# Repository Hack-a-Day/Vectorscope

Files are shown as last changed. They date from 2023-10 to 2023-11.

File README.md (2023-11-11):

# Hackaday Superconference 2023 Vectorscope Badge

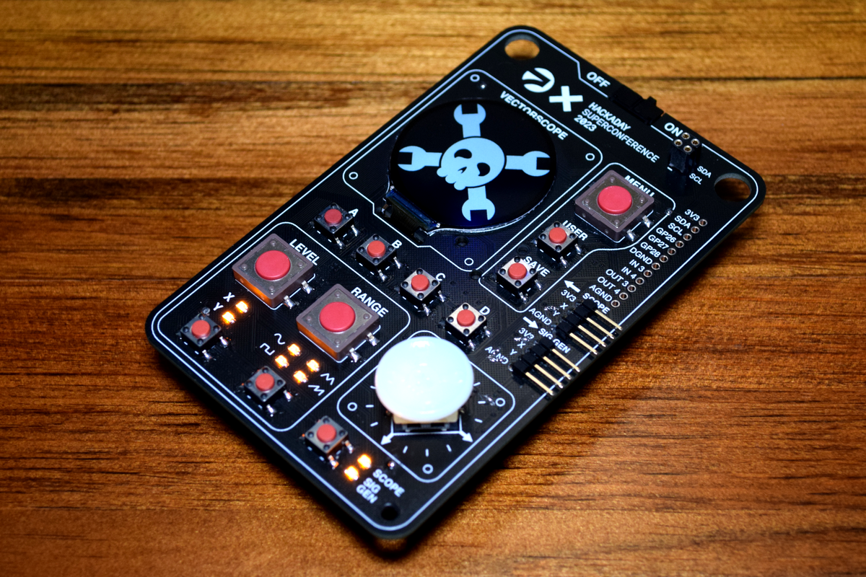
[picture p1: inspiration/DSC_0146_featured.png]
Vectorscope


## Related articles

* [Hackaday Teaser](https://hackaday.com/2023/10/18/2023-hackaday-supercon-badge-welcome-to-the-vectorscope/)
* [Hackaday Printable case](https://hackaday.com/2023/10/29/packing-for-supercon-heres-a-printable-case-for-your-badge/)

## Getting started

### IDEs

#### Thonny

This is a relatively simple IDE, more or less designed specifically for MicroPython, and does most of the stuff you would need, without hiding functionality.

It's pretty easy to install at get started with, not least because you can access and open up files directly on the badge, edit them and save them back on the badge.

See the [Thonny getting started](setup/README.md#Thonny) for a little more info.

#### VSCode and the MicroPico extension

If you already use VSCode, the MicroPico extension and a few other recommended extensions might be an option, especially if you are used to have projects and work with both a set of files on you computer and on the badge. There is a bit more setup required to get going, but you get a bit more functionality in areas like code completion and direct access to documentation for various functions.

See the [VSCode getting started](setup/README.md#VSCode) for a little more info and setup help.

#### Your favorite text editor and mpremote

If you don't like integrades development environments (IDEs), you can also use your favorite text editor and mpremote for communication with the badge.

We have a few [tips and tricks with mpremote](setup/README.md#mpremote) to get you started.

## Repository overview

### Firmware

This folder has the MicroPython firmware for the Raspberry Pi Pico on the badge in a special edition, that includes the driver for the GC9A01 display controller and some of the latest additions needed for DMA on the RP2040.

The ```.uf2``` file can be used to restore the badge, if you have tried other code and want to revert back to the original state. In addition to the ```.uf2``` firmware file, you will also need the original MicroPython code and assets for a full restore.

### Hardware

The hardware folder is where you will find all the details about the main PCB, the expansion board and the parts that are on the main board. There is schematics as a few images, and data sheets for the parts used. Especially the Pico [datasheet](hardware/datasheets/pico-datasheet.pdf?raw=true) or the [pinout](hardware/datasheets/pico_pinout.png?raw=true) can be usefull as a references, if you want to have a go at doing some hacks outside of the normal.

The design is done in Altium Circuit Maker and in addition to the [board file](hardware/vectorscope/vectorscope.CSPcbDoc?raw=true), there are also Gerbers, drill files and a BOM, in case you want to make your own or maybe just have a peak and check some traces.

There is also a WiP (Work in Progress) version of the [board file i KiCad format](hardware/vectorscope/vectorscope.kicad_pcb?raw=true). It's not perfect as some of the conversion didn't go perfect (eg. incorrect ground plane size and connections), but for mechanical use (eg. case design) it should be OK, though not all 3D models are available in the default KiCad repository.

If you want to build you own based on the Gerbers here some notes:
- T1 needs to be solderd flipped (deadbug) and rotated. Like in this image. You see the backside of the Fet. Pins need to get bend a little bit.

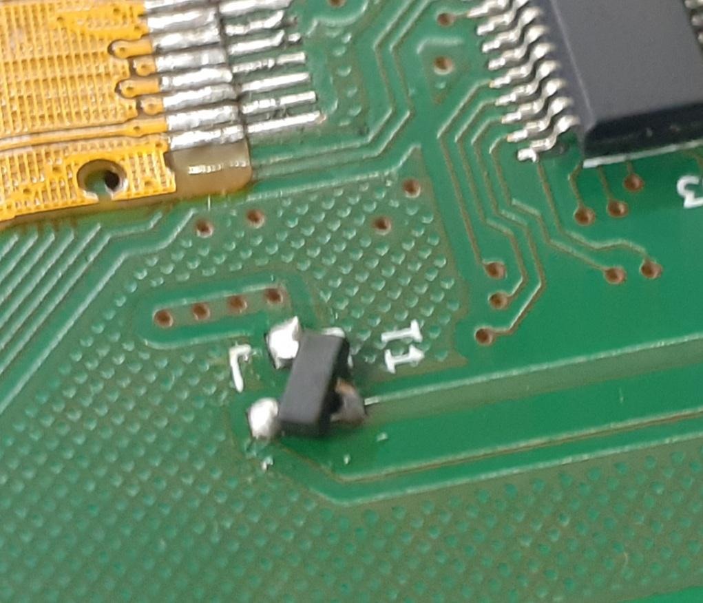
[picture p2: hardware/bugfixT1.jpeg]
bugFixT1


### Inspiration

We'd been thinking of doing something analog this year, because we've been heavily digital with the [2019 FPGA badge](https://hackaday.com/2019/11/04/gigantic-fpga-in-a-game-boy-form-factor-2019-supercon-badge-is-a-hardware-siren-song/) and [last year's virtual retrocomputer](https://hackaday.com/2022/10/12/the-2022-supercon-badge-is-a-handheld-trip-through-computing-history/).  [Sebastian Holzapfel]'s [Eurorack FPGA frontend](https://hackaday.com/2023/02/13/an-open-hardware-eurorack-compatible-audio-fpga-front-end/) showed us how to abuse the AK4619 ADC/DAC chip for DC voltage purposes, and our path was clearer still.  

Finally, [Schneider] showed us the prototypes for the [flow3r badge for this summer's Chaos Camp](https://flow3r.garden/) in [Berlin](https://hackaday.com/2023/03/27/hackaday-berlin-was-bonkers/), and we needed to make a vintage round-screen scope.  Besides, we'd been looking for an excuse to try out those round screens since seeing [Scott Bezek]'s [SmartKnob](https://github.com/scottbez1/smartknob).  How could we resist?

## Related projects

- [BASIC-2 enclosure](https://github.com/softegg/supercon-2023-badge-enclosure/tree/main/BASIC-2) by Tina Belmont

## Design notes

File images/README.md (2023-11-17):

Here you'll find some `uf2` images that you can copy directly to the badge when it's mounted in bootloader / USB-disk mode.  (Hold the Pico's boot button while plugging in.)

The images in micropython_compiled/ are a preview version of v1.22.0, with a driver for the GC9A01 screen and pull release for DMA support compiled in.  This is here really just in case you want to play around, or if you've soldered on a Pico W, which requires its own firmware.

The Supercon image includes our modified Micropython and all of the various python code that makes it run.

Note that flashing the Supercon `uf2` will probably wipe anything you have on the device, so save your work first.  Heck, save your work right now anyway.  You never know!

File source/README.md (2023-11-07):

# Supercon 2023 Source Code

This directory contains the source files for the 2023 Supercon Badge. When possible, changes from the initial day-one release are listed below.

## Changes
- supercon_menu.py: Fixed crash in scope mode
- led.py: Added from Vector OS docs
- keyboardrepeat.py - Added from Vector OS docs

- Tagged as V1.0

- Added BETA/*.py files to source and removed BETA directory
  Note: this means the UF2 matches V1.0 not current
  development files

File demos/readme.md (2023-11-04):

VectorOS Demos
==============

* blinker.py - Obligatory LED blinker
* csvdemo.py - Paste numbers from a spreadsheet, view on scope
* csvfile.py - Read data.dat (Y values), view on scope
* csvfilexy.py - Read dataxy.dat (X,Y values), view on scope
* hello.py - File from tutorial
* life.py - Slow game of life (needs work)
* simple.py - Another LED blinker (very simple)

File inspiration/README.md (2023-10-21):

# Vectorscope Inspiration

We'd been thinking of doing something analog this year, because we've been heavily digital with the [2019 FPGA badge](https://hackaday.com/2019/11/04/gigantic-fpga-in-a-game-boy-form-factor-2019-supercon-badge-is-a-hardware-siren-song/) and [last year's virtual retrocomputer](https://hackaday.com/2022/10/12/the-2022-supercon-badge-is-a-handheld-trip-through-computing-history/).  [Sebastian Holzapfel]'s [Eurorack FPGA frontend](https://hackaday.com/2023/02/13/an-open-hardware-eurorack-compatible-audio-fpga-front-end/) showed us how to abuse the AK4619 ADC/DAC chip for DC voltage purposes, and our path was clearer still.  

Finally, [Schneider] showed us the prototypes for the [flow3r badge for this summer's Chaos Camp](https://flow3r.garden/) in [Berlin](https://hackaday.com/2023/03/27/hackaday-berlin-was-bonkers/), and we needed to make a vintage round-screen scope.  Besides, we'd been looking for an excuse to try out those round screens since seeing [Scott Bezek]'s [SmartKnob](https://github.com/scottbez1/smartknob).  How could we resist?

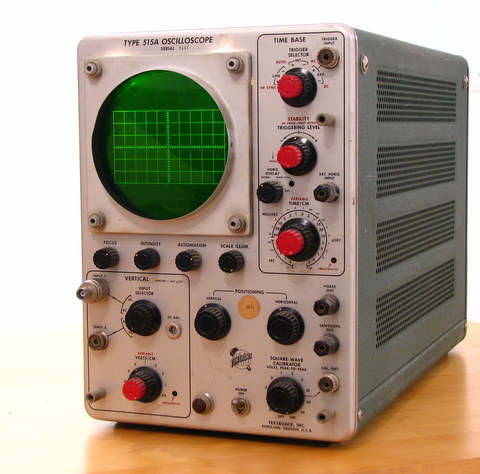
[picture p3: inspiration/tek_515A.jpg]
Tek 515A


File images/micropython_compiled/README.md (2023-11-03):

Firmware images for the Micropython builds for the badge.  These are just the Micropython, none of our badge code.

Note these come in Pico and Pico_W flavors.  Choose wisely.

These are compiled with [gc9a01_mpy](https://github.com/russhughes/gc9a01_mpy) screen driver and [a recent pull request](https://github.com/micropython/micropython/pull/7641) that provides interrupt request support for the DMA subsystem.

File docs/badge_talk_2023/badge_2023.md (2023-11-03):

# Supercon 2023: The Vectorscope Badge

# Overview

## The Badge

- What is It?

- How Does it Work?

- Can I Hack It?

## Inspiration: Analog



## One Badge, Two Parts

- Vectorscope: 30 kHz "scope"

- Signal Generator: Driven by code 

- X/Y outputs, X/Y inputs (0 V - 3 V)

## Vectorscope

- Fake phosphor display 

- "No User-Serviceable Parts Inside"

- AK4619 Codec chip (`codec.py`)

- ADC in, 16 frames of 1024 samples (16-bit X/Y)

- Insane DMA/PIO Machine (`pixel_pusher.py`)

- Twelve lines of user-space code (`vectorscope.phosphor()`)

## Signal Generator

- DAC out

- Limitations: 30 kHz, ringy filter, one CPU core

- X/Y buffers, 256 points @ 16 bits, interleaved and pushed out

- This is your playground (`waveform.py`)

## Signal Generator "API"

- `v.wave.point(x,y)`  

- `v.wave.packX(list)`, `v.wave.packY(list)`

- `v.wave.outBuffer_ready`: 

- write False, wait till True

## Operating System

- Vectoros!

- Runs menu system

- Buttons and LEDs

- Uses `asyncio`: define functions `async` and be sure to yield

- Lets you map your code to `A/B/C/D.py`

## Micropython

- Why Micropython?

- Interactive REPL to control vectorscope is awesome

- Two cores: one just for you

- Filesystem

- Secret trick: Hold down the [User] Button on boot

## Creature Comforts

- Thonny IDE: configure to use badge, done

- mpremote: for the CLI aficionado

- `mp run file.py`, `mp cp *.py :`, `mp mount .`

- `picotool save -a your_image.uf2`

- VS Code stubs

## Many Ways to Play

- Use `vectorscope.wave`, funny graphics and/or sounds

- Go analog!

- Tweak vectorscope 

- Don't use vectorscope: GC9A01_mpy library compiled in

- Blow Micropython away and start from scratch (but: codec, screen, keys)

# Under the Hood

## Credits

- Hackaday Team: Elliot and Al and Tom

- Voja Antonic

- Design Lab: Giovanni, Majenta, Bruce, Keno, and Team 

## Tales of Woe 

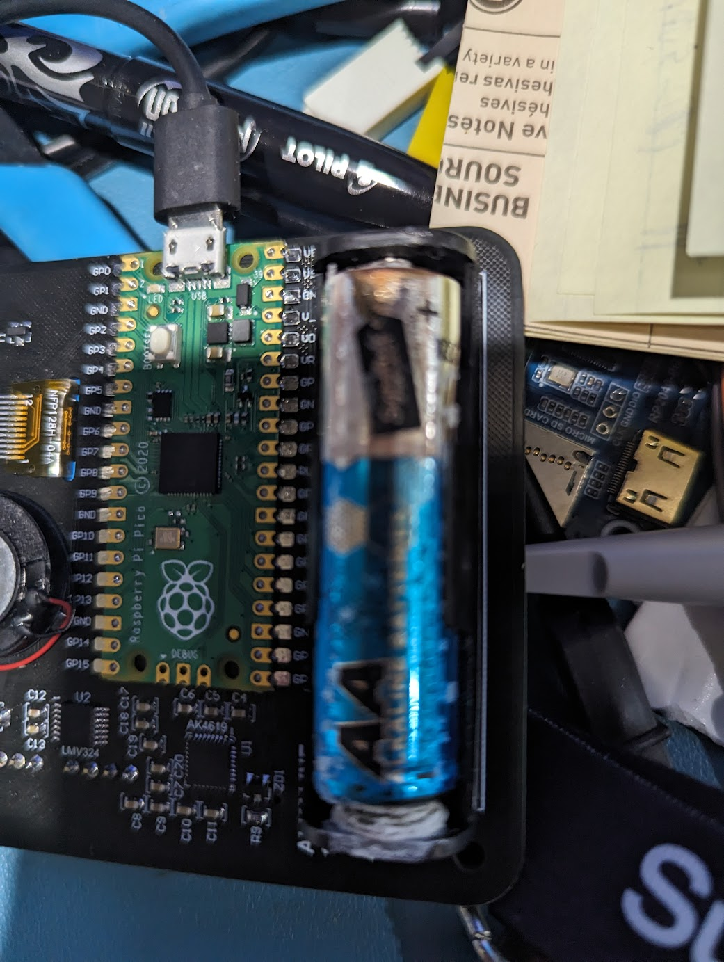
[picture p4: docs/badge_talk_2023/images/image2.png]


## Powers of Ten

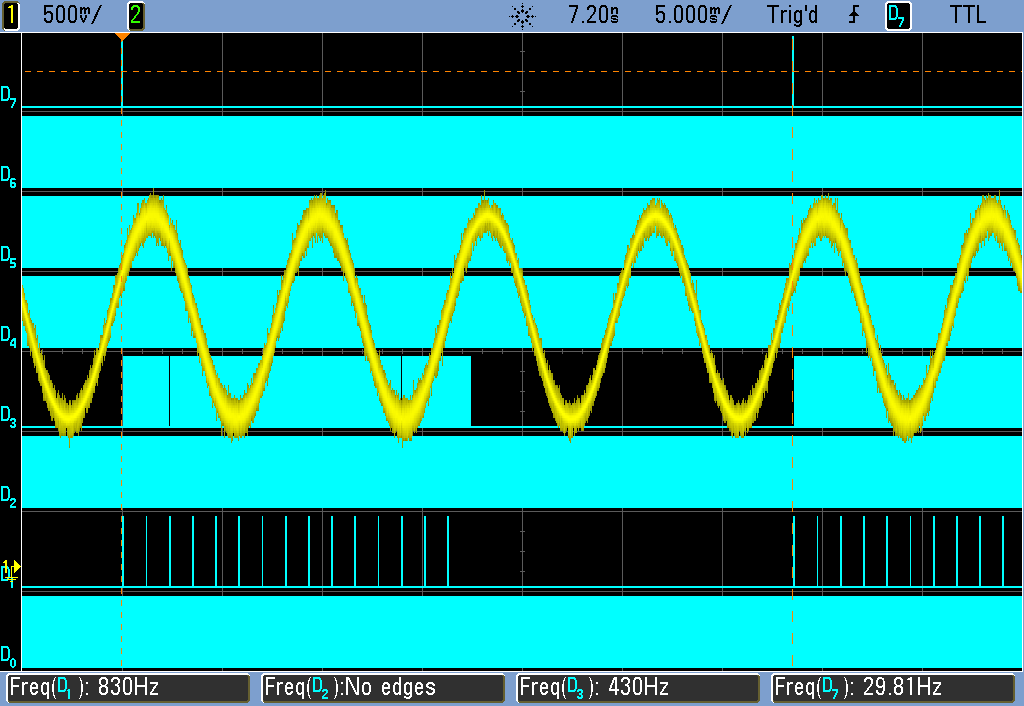
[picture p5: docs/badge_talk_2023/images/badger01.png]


## 10 ms
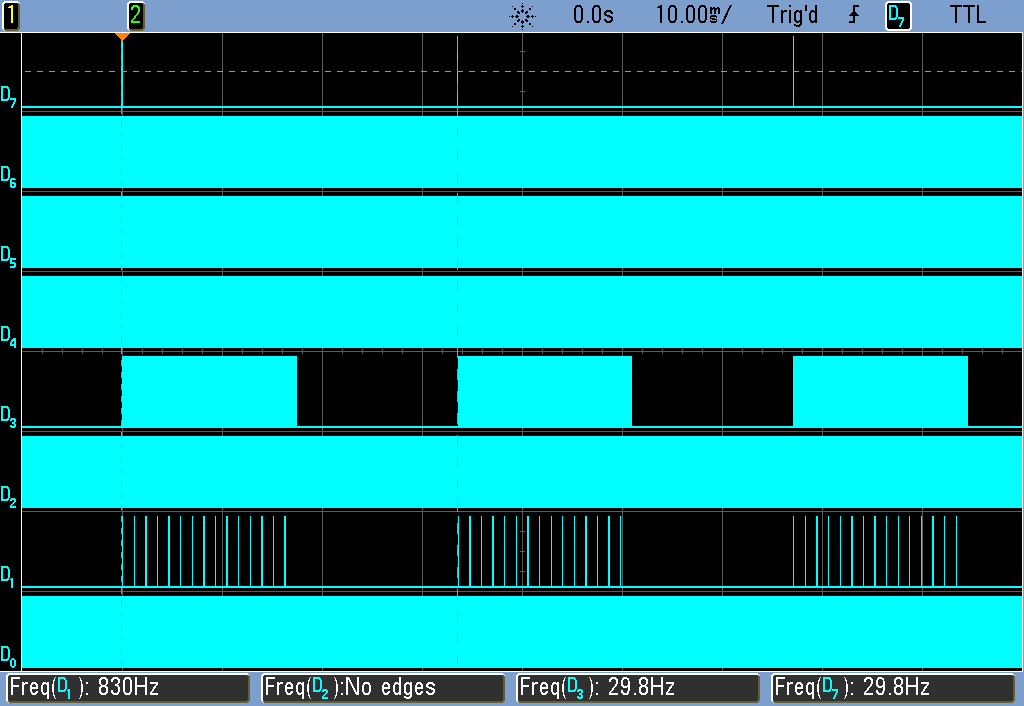
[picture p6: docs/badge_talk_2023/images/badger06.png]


## 1 ms
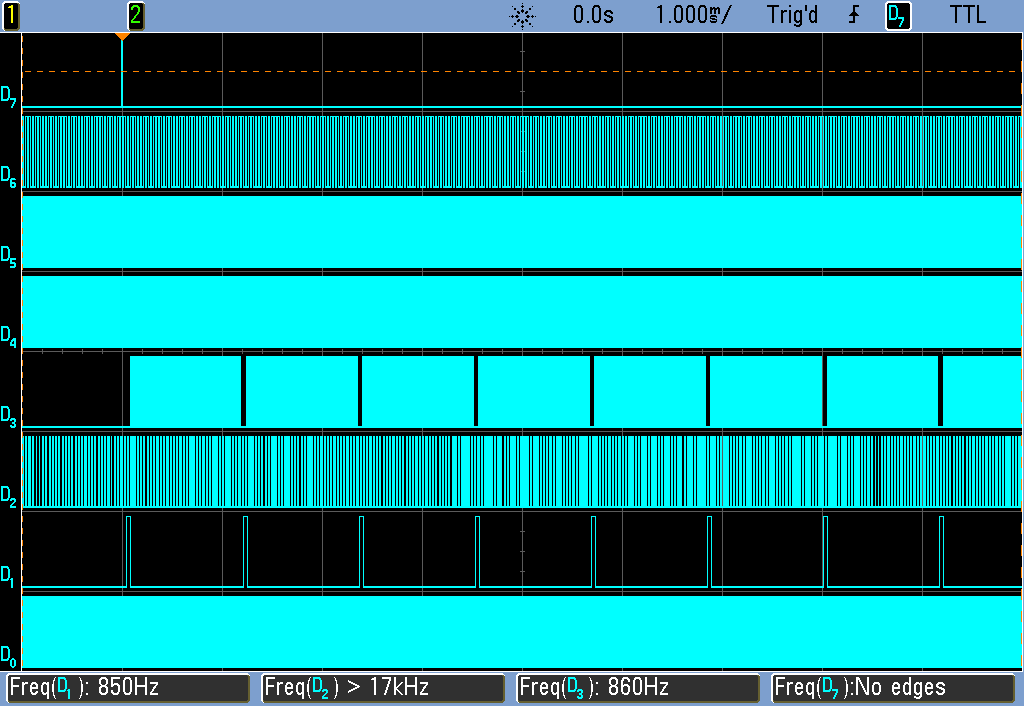
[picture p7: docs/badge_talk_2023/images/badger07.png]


## 100 us
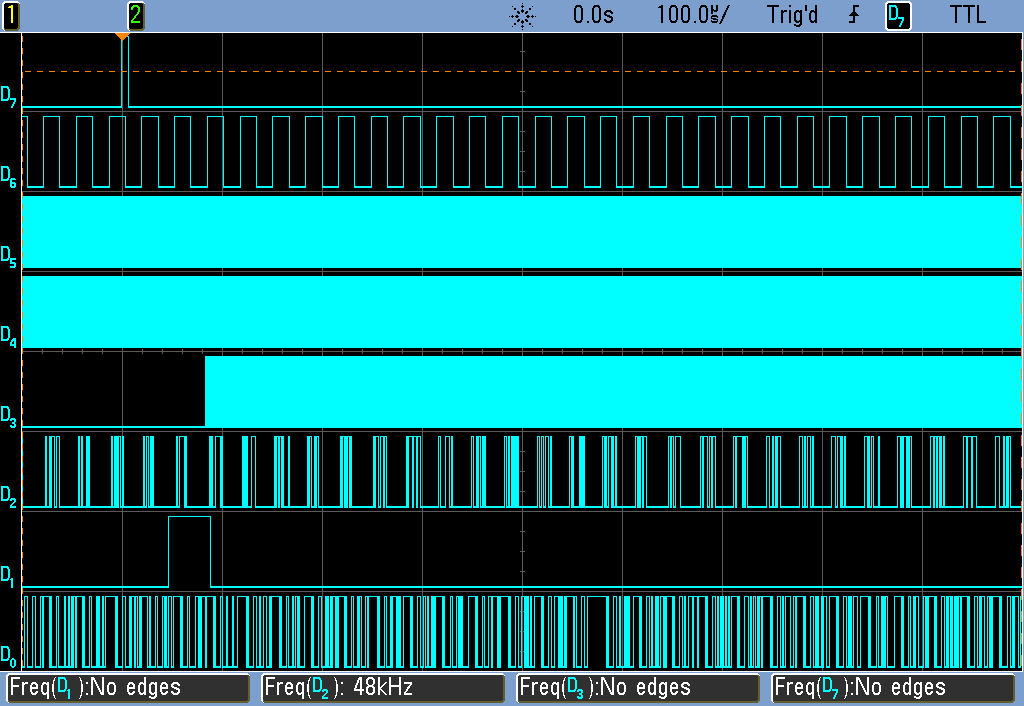
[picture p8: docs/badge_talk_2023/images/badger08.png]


## 10 us
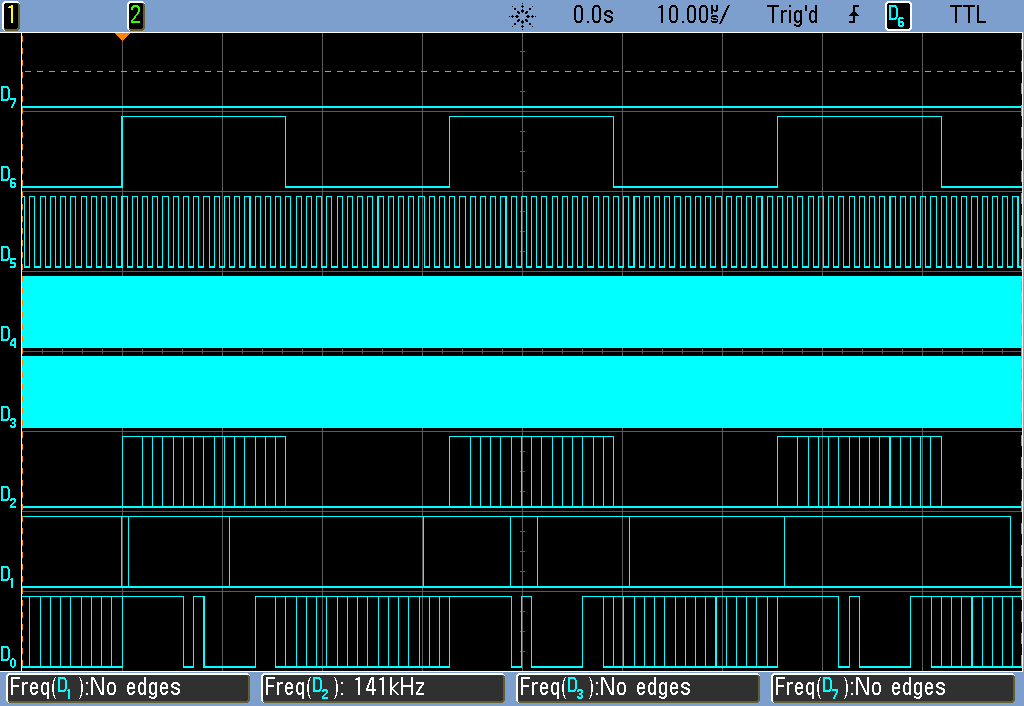
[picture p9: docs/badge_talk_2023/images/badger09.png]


## 1 us
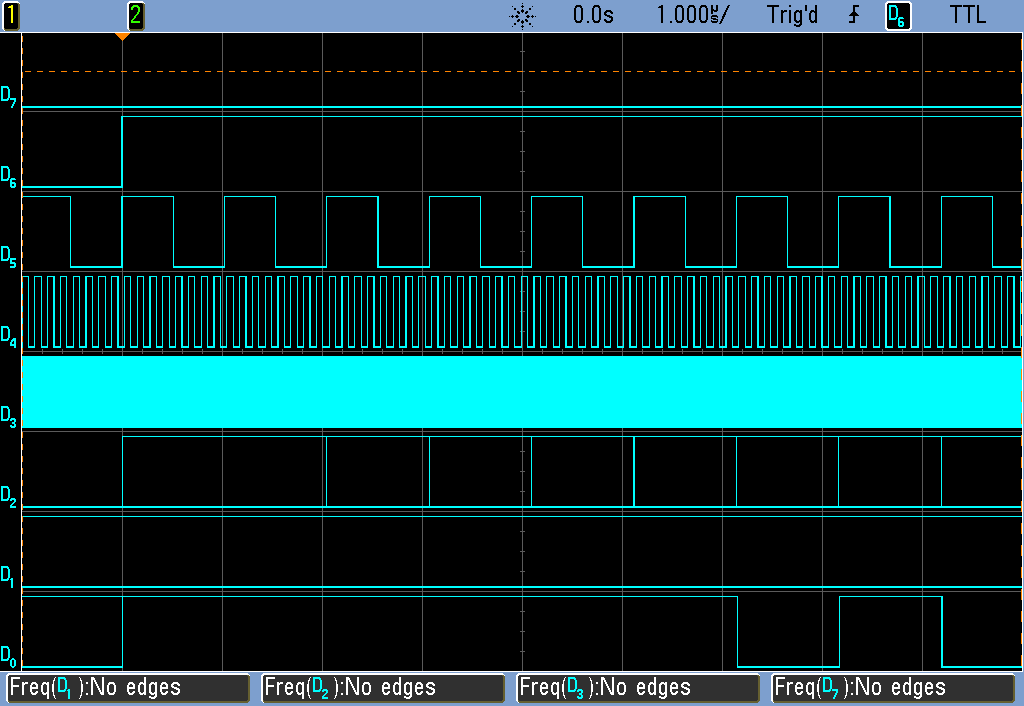
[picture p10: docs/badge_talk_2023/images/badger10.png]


## 100 ns
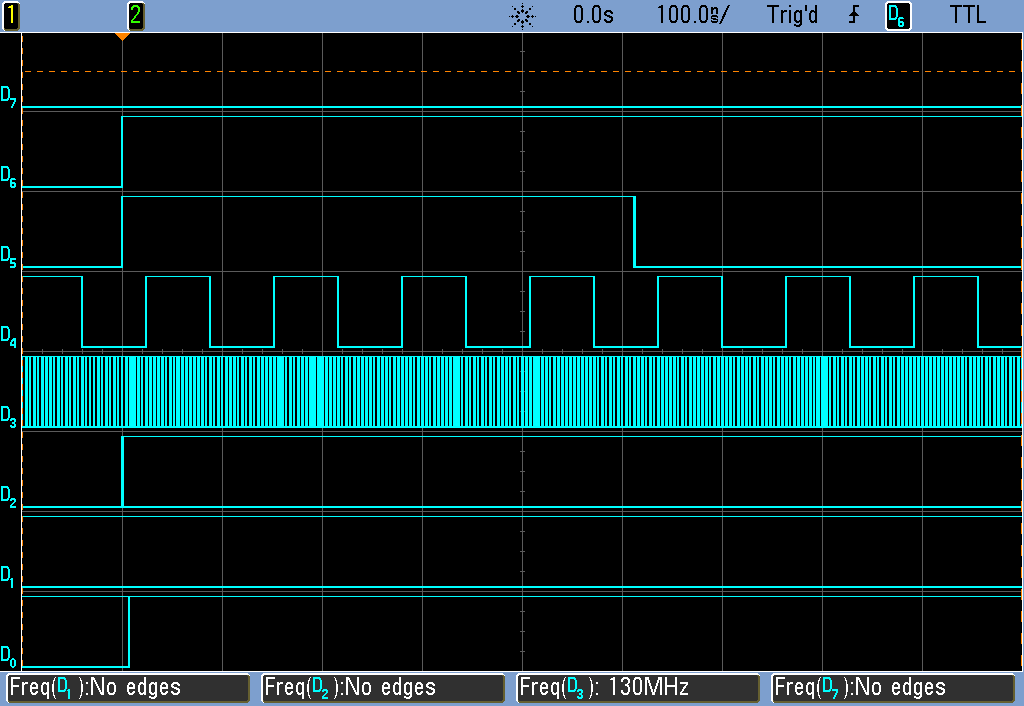
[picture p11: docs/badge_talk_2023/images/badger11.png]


## 10 ns
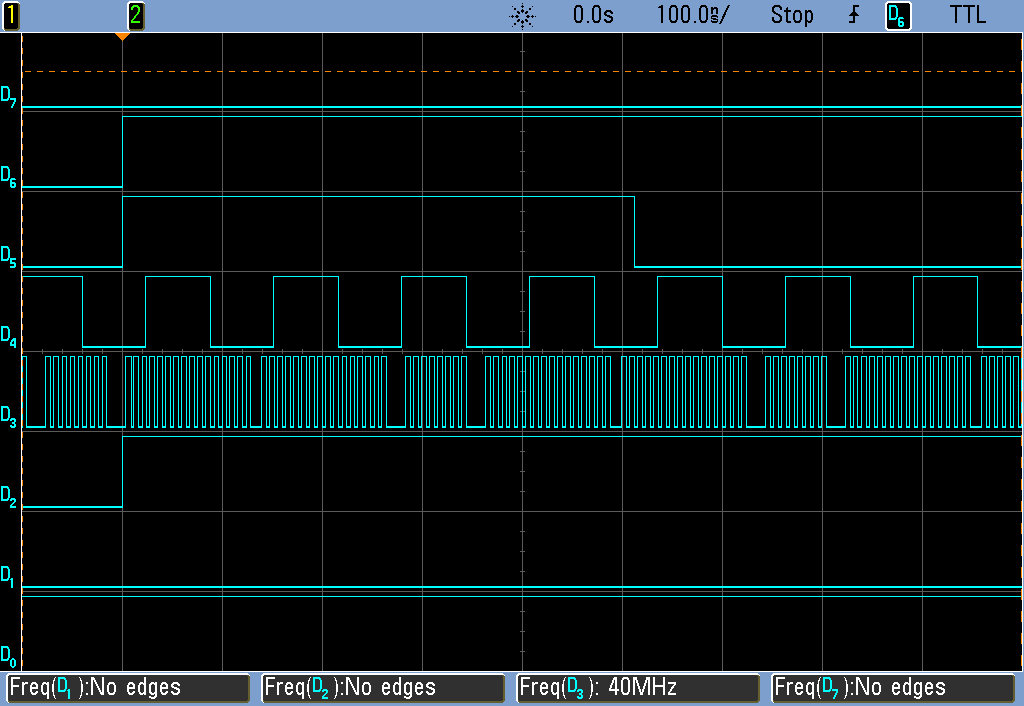
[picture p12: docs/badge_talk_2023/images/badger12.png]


## 1 ns
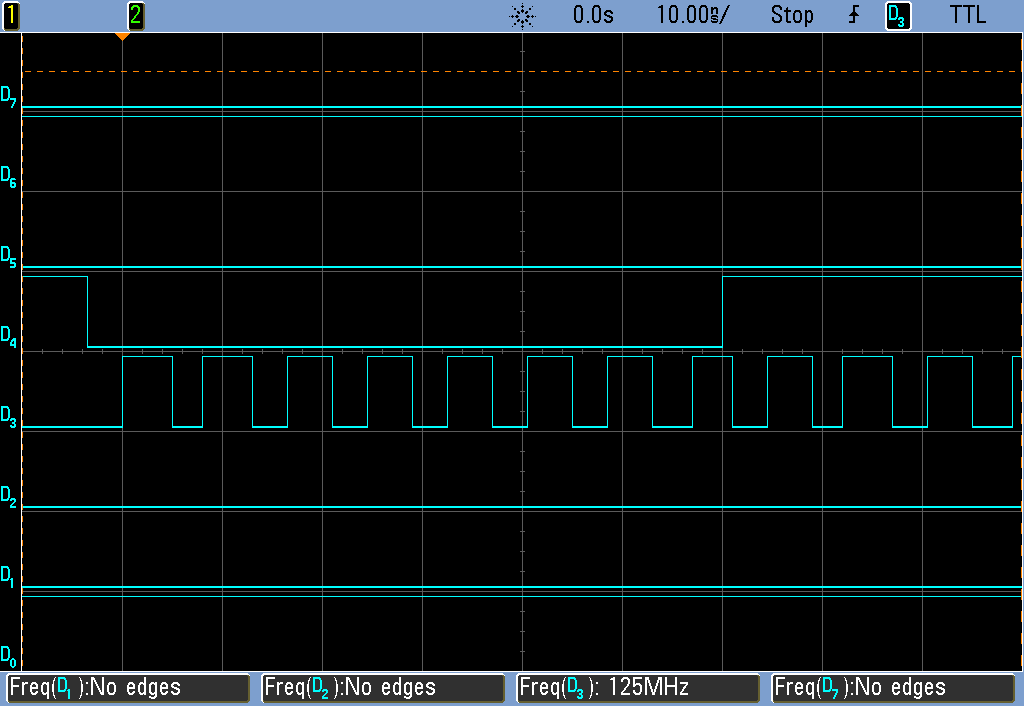
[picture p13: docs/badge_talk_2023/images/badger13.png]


## The DMA/PIO Machine

- DMA reads from one location to another

- DMA and memory is Turing complete

- DMA counter

## Pixel Pusher

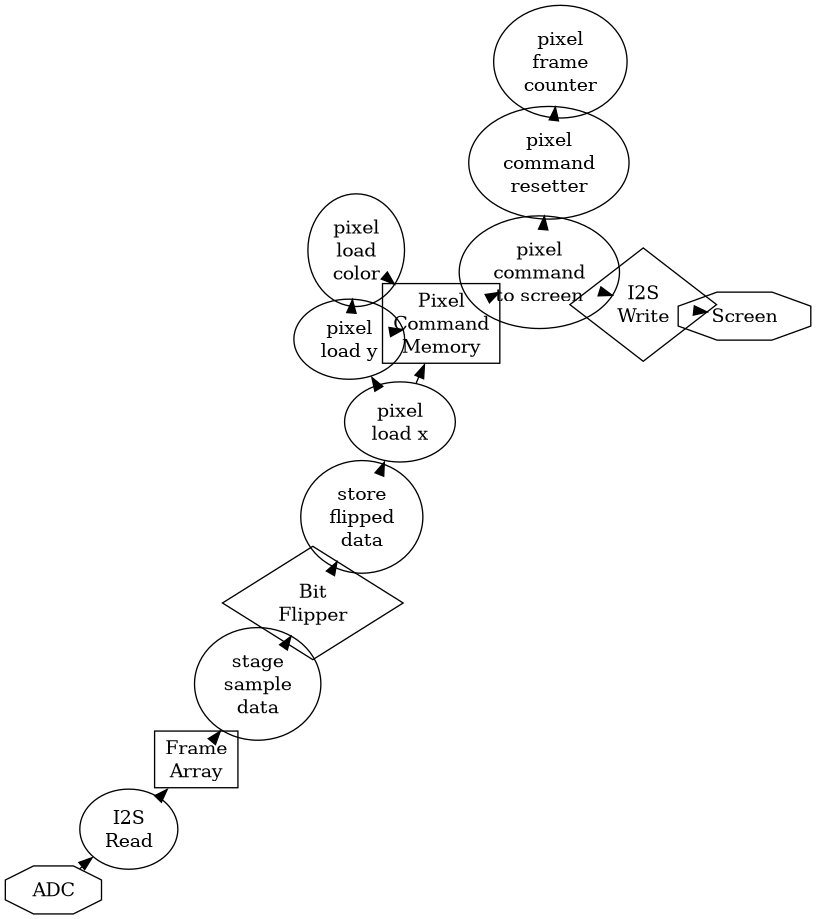
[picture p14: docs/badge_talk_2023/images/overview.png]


# Badgers!

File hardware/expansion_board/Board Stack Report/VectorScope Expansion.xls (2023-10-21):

Board Stack Report
Stack Up |  | Layer Stack
Layer | Board Layer Stack | Name | Material | Thickness | Constant
1 |  | Top Paste
2 |  | Top Overlay
3 |  | Top Solder | Solder Resist | 1.00mil | 3.5
4 |  | Top Layer | Copper | 1.40mil
5 |  | Dielectric 1 | FR-4 | 60.00mil | 4.6
6 |  | Bottom Layer | Copper | 1.40mil
7 |  | Bottom Solder | Solder Resist | 1.00mil | 3.5
8 |  | Bottom Overlay
9 |  | Bottom Paste
 | Height : 64.80mil

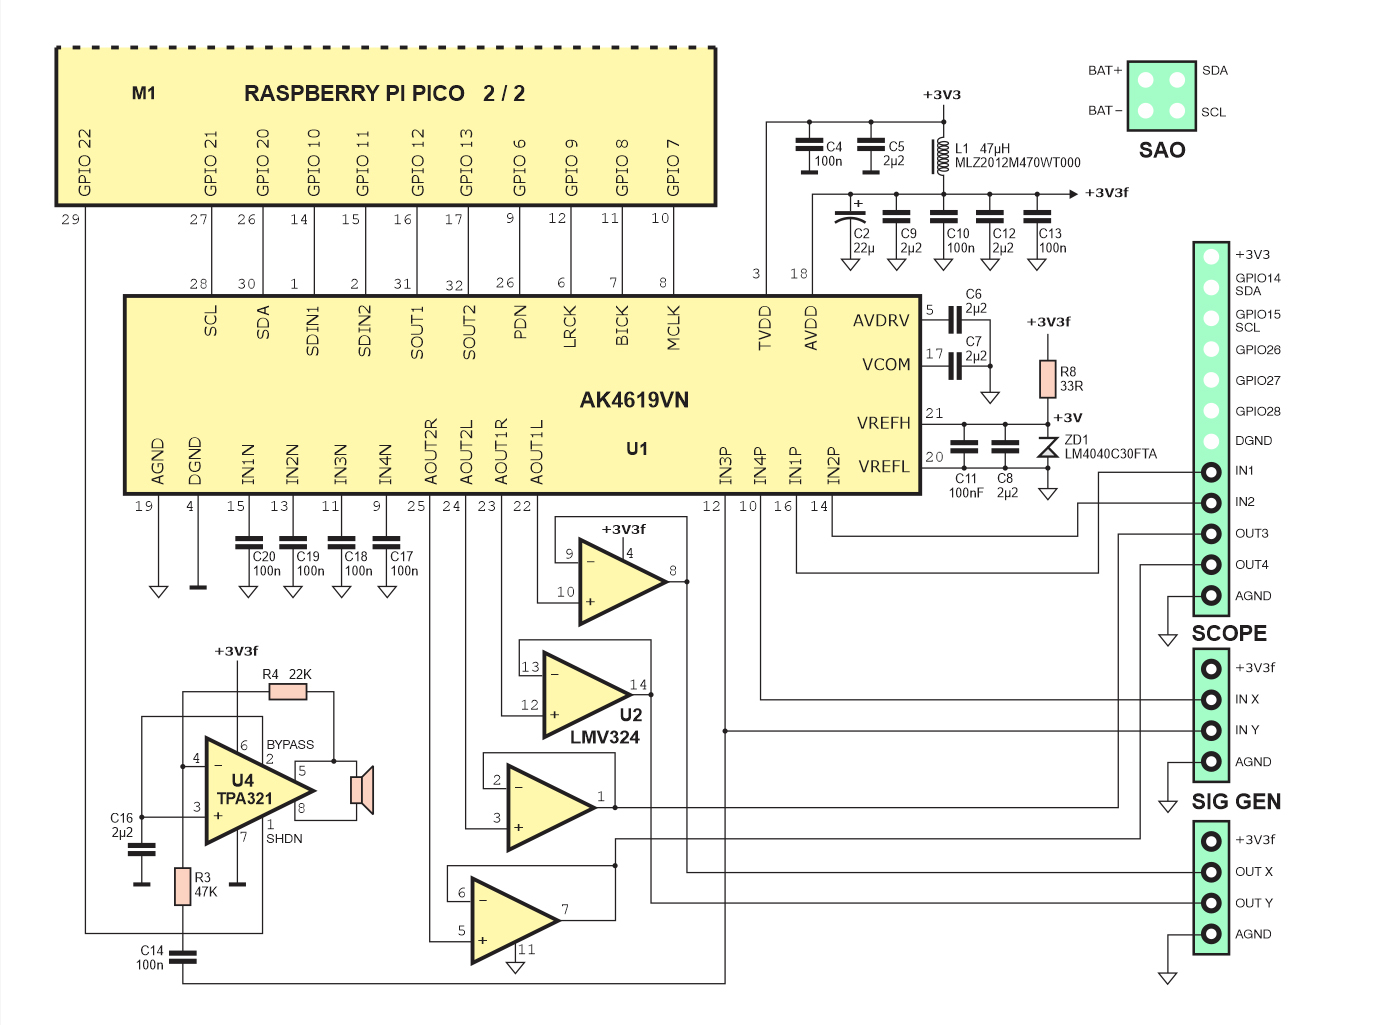
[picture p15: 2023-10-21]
hardware/vectorscope/VectorScope SCH 2.jpg

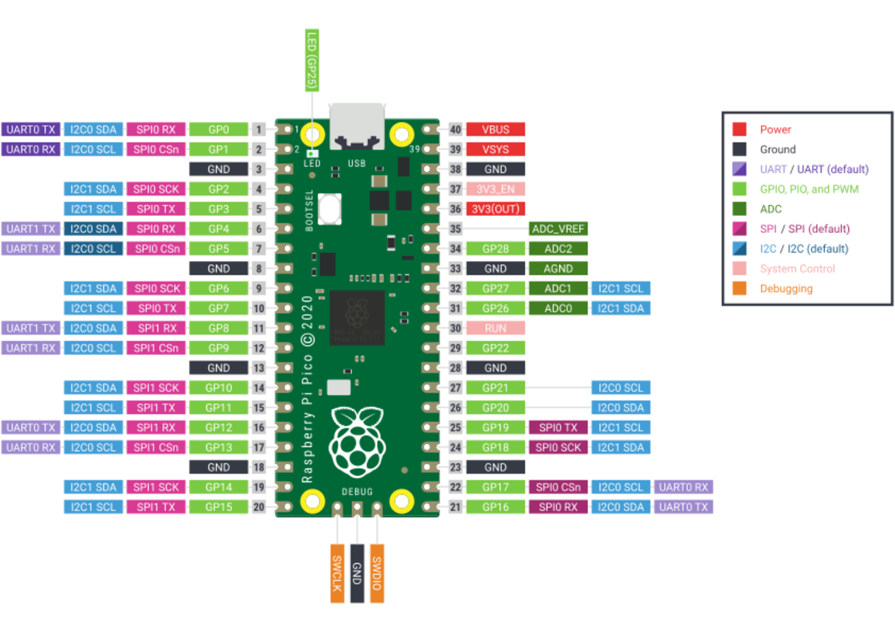
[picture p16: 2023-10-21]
hardware/datasheets/pico_pinout.png

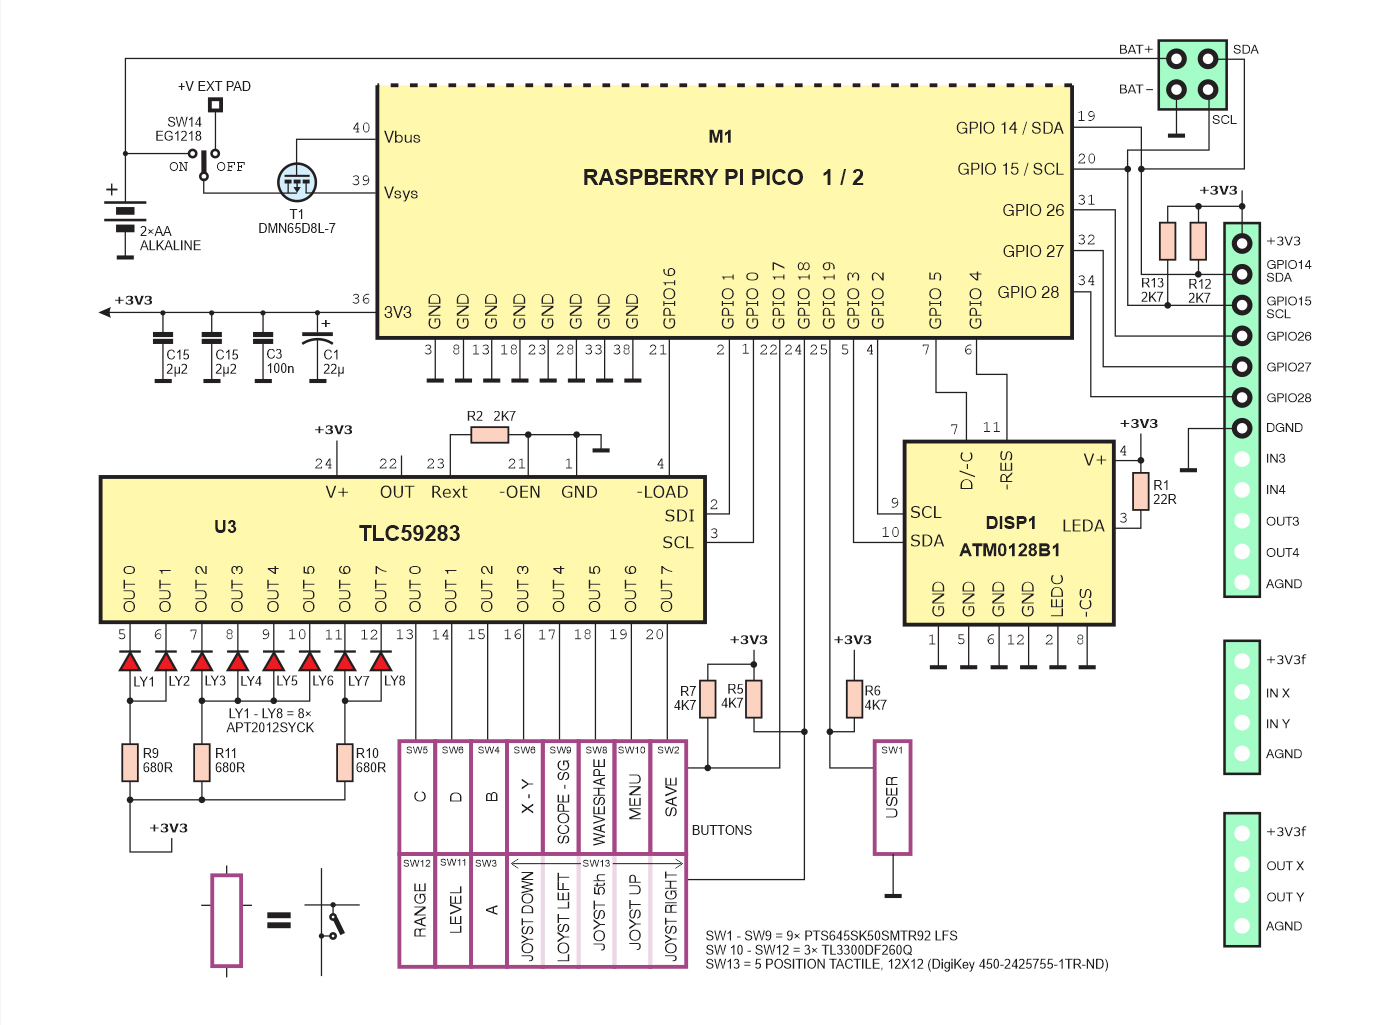
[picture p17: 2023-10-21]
hardware/vectorscope/VectorScope SCH 1.jpg

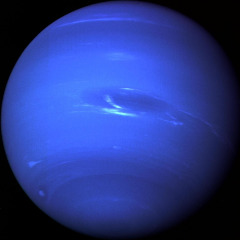
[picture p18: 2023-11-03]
source/pl_neptune.jpg

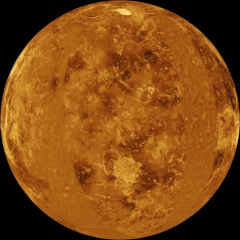
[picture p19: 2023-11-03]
source/pl_venus.jpg

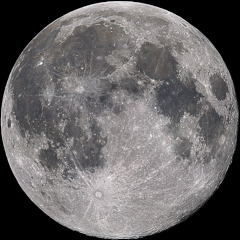
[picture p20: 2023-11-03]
source/pl_moon.jpg

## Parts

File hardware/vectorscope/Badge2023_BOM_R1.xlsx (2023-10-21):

Confirmed | Board | Ref | Item | Description | MFR | MFPN | Dist | DPN | Qty Per Unit | PCBA | LAYER | Note
x | BadgeBottom | M1 | PICO MODUL |  |  |  |  |  | 1 | SMD | BOTTOM
x | BadgeTop | Disp1 | TFT Display | 1.28 inch round TFT display |  | SUN-0827 |  |  | 1 | NOPOP | TOP | TH SOLDER
x | BadgeTop | LY 1, LY 2, LY 3, LY 4, LY 5, LY 6, LY 7, LY 8 | LED YELLOW | LED YELLOW CLEAR CHIP 0805 SMD | Kingbright | APT2012SYCK | Digi-key | 754-1134-1-ND | 8 | SMD | TOP
x | BadgeTop | SW10, SW11, SW12 | BUTTON 12x12 | Tactile Switch SPST-NO Top Actuated SMD | JS Switch | TL3300DF260Q | Digi-key | EG4907CT-ND | 3 | SMD | TOP
x | BadgeTop | SW1, SW2, SW3, SW4, SW5, SW6, SW7, SW8, SW9 | BUTTON 6x6 | SWITCH TACTILE SPST-NO .05A 12V | C&K | PTS645SK50SMTR92 LFS | Digi-key | CKN9087TR-ND | 9 | SMD | TOP
x | BadgeTop | SW13 | Joystick | 5 POSITION TACTILE, 12X12 | TE Connectivity ALCOSWITCH | 5 POSITION TACTILE, 12X12 | Digi-key | 450-2425755-1TR-ND | 1 | SMD | TOP
x | BadgeBottom | SW14 | SWITCH | SWITCH SLIDE SPDT 200mA 30V | E-Switch | EG1218 | Digi-key | EG1903-ND | 1 | NOPOP | BOTTOM | TH SOLDER
x | BadgeBottom | U1 | CODEC | Audio Codec | Asahi Kasei Microdevices/AKM | AK4619VN | Digi-key | 974-AK4619VNCT-ND | 1 | SMD | BOTTOM
x | BadgeBottom | U2 | OpAmp | IC OPAMP GP 4 CIRCUIT 14TSSOP | Texas Instruments | LMV324AIPWR | Digi-key | 296-51366-1-ND | 1 | SMD | BOTTOM
x | BadgeBottom | U3 | Shift Register | IC LED DRIVER LINEAR 45MA 24SSOP | Texas Instruments | TLC59283DBQR | Digi-key | 296-30546-1-ND | 1 | SMD | BOTTOM
x | BadgeBottom | U4 | Audio Amplifier | IC AMP MONO 700MW 8SOIC | Texas Instruments | TPA321DR | Digi-key | 296-46365-1-ND | 1 | SMD | BOTTOM
x | BadgeBottom | T1 | MOSFET | MOSFET P-CH 20V 4.2A SOT23 | Diodes Incorporated | DMG2305UX-7 | Digi-key | DMG2305UX-7DICT-ND | 1 | SMD | BOTTOM
x | BadgeBottom | ZD1 | ZenerDiode | IC VREF SHUNT 0.5% SOT23 | Diodes Incorporated | LM4040C30FTA | Digi-key | LM4040C30FTADICT-ND | 1 | SMD | BOTTOM
x | BadgeBottom | C3, C4, C10, C11, C13, C14, C17, C18, C19, C20 | CAPACITOR | CAP CER 0.1UF 16V X7R 0603 | Samsung Electro-Mechanics | CL10B104KO8NNNC | Digi-key | 1276-1005-1-ND | 10 | SMD | BOTTOM
x | BadgeBottom | C5, C6, C7, C8, C9, C12, C15, C16 | CAPACITOR | CAP CER 2.2UF 16V X5R 0603 | Samsung Electro-Mechanics | CL10A225KO8NNNC | Digi-key | 1276-1040-1-ND | 8 | SMD | BOTTOM
x | BadgeBottom | C1,C2 | Tantalum Capacitor | Tantalum Capacitor 0805 | TAJB226K016RNJ | M20-9960445 | Digi-key | 478-1682-1-ND | 2 | SMD | BOTTOM
x | BadgeBottom | R1 | RESISTOR | Resistor 22R 0805 | YAGEO | RC0603JR-0722RL | Digi-key | 311-22GRCT-ND | 1 | SMD | BOTTOM
x | BadgeBottom | R8 | RESISTOR | Resistor 330R 0805 | YAGEO | RC0603JR-13330RL | Digi-key | 13-RC0603JR-13330RLCT-ND | 1 | SMD | BOTTOM
x | BadgeBottom | R9, R10, R11 | RESISTOR | Resistor 680R 0805 | YAGEO | RC0603JR-13680RL | Digi-key | 13-RC0603JR-13680RLCT-ND | 3 | SMD | BOTTOM
x | BadgeBottom | R2, R5, R6, R7, R12, R13 | RESISTOR | Resistor 2K7 0805 | YAGEO | RES 2.7K OHM 5% 1/10W 0603 | Digi-key | 311-2.7KGRCT-ND | 6 | SMD | BOTTOM
x | BadgeBottom | R4 | RESISTOR | Resistor 22K 0805 | YAGEO | RC0603FR-1022KL | Digi-key | 13-RC0603FR-1022KLCT-ND | 1 | SMD | BOTTOM
x | BadgeBottom | R3 | RESISTOR | Resistor 47K 0805 | YAGEO | RES 47K OHM 1% 1/10W 0603 | Digi-key | 13-RC0603FR-1347KLCT-ND | 1 | SMD | BOTTOM
x | BadgeTop | CON1 | CONNECTOR | CONN HEADER R/A 4POS 2.54MM | Harwin Inc. | CONN HEADER R/A 4POS | Digi-key | 952-3286-ND | 2 | NOPOP | TOP | TH SOLDER
x | Expansion | CON1E | CONNECTOR | CONN HDR 4POS 0.1 TIN PCB R/A | Sullins Connector Solutions | PPTC041LGBN-RC | Digi-key | S5440-ND | 2 | NOPOP | TOP | TH SOLDER
 | BadgeTop | CON2 | CONNECTOR | CONN SOCKET 4POS 0.1 GOLD PCB | Preci-Dip |  | Digi-key | 1212-1227-ND | 1 | NOPOP | TOP | TH SOLDER
 | BadgeBottom | BH1, BH2 | BATTERY HOLDER | BATT HOLDER AA 1 CELL PC PIN | Keystone Electronics | #2460 | SAGER | https://www.sager.com/product/2460-keystone-electronics/33130 | 2 | NOPOP | BOTTOM | TH SOLDER
 | BadgeBottom | SP1 | SPEAKER | SPEAKER 8OHM 800MW 20mm 8Ohm | Taoglas Limited | SPKM.20.8.A | Digi-key | 931-SPKM.20.8.A-ND | 1 | NOPOP | BOTTOM | TH SOLDER
 | BadgeBottom | L1 | Choke 0805 | FIXED IND 47UH 170MA 3.7 OHM 0805 | TDK Corporation | MLZ2012M470WT000 | Digi-key | 445-6400-1-ND | 1 | SMD | BOTTOM

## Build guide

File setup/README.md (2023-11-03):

# Setting up your development environment

## Thonny

Go to [the Thonny website](https://thonny.org/) and download the version for your operating system. It's available for Windows, macOS (both Intel and Apple Silicon), and for various versions of Linux.

After installation, you start up the application and choose the serial port that your badge is connected to (if it isn't auto detected), and you can start opening and editing the python files.

When Thonny is connected to the badge, you will have access to the REPL in a terminal (when the main code isn't running), and you can both copy your code over to the badge and run it after a reset, or you can simply run the code you have open in Thonny directly, without saving it to the badge.

If you are testing out different things, simply opening a file and running it on the badge is a quick way to experiment. If you only want to try out a single command, runnig it in the REPL is another very quick way to get started and test stuff.

## VSCode

After [installing VSCode](https://code.visualstudio.com/Download), you need to install the [MicroPico extension](https://marketplace.visualstudio.com/items?itemName=paulober.pico-w-go) and that is easiest done via the extension manager inside VSCode. Simply search for "MicroPico", install the extension and probably also the recommended additional extensions.

When you have the extension installed, you can create a new project (open a new folder), and run ```> MicroPico > Configure Project command``` via ```Ctrl+Shift+P``` (or the equivalent on your platform). This will setup the project as a MicroPico project and add a ```.vscode``` folder, with a bit of configuration.

Inside this hidden folder is some project settings and a link to stub files used for IntelliSense and code completion. This is for a regular Raspberry Pi Pico and will get you most of the way, but if you also want code completion for the display driver used on the badge (GC9A01), you can add the [Vectorscope folder](Vectorscope/) and it's content to this ```.vscode``` folder next to the ```Pico-W-Stub``` folder either by copying in the folder or by creating a symlink to the folder in this repository, if you have it checked out. To have MicroPico use these stubs edit the ```settings.json``` to also include this folder:

```json
{
    "python.linting.enabled": true,
    "python.languageServer": "Pylance",
    "python.analysis.typeCheckingMode": "basic",
    "python.analysis.diagnosticSeverityOverrides": {
        "reportMissingModuleSource": "none"
    },
    "python.analysis.typeshedPaths": [
        ".vscode/Pico-W-Stub",
        ".vscode/Vectorscope",
    ],
    "python.analysis.extraPaths": [
        ".vscode/Pico-W-Stub",
        ".vscode/Vectorscope",
    ],
    "micropico.syncFolder": "",
    "micropico.openOnStart": true
}
```

The new lines are line 10 and line 14, but remember to also add a comma after the preceding lines, to keep the json syntax valid.

## mpremote

The official [documentation for mpremote](https://docs.micropython.org/en/latest/reference/mpremote.html) has info on how to install and also detailed instructions for all the features.

It's really not that long a read, but the TLDR is here:

Install via ```pip install --user mpremote``` and then you can invoke the program with ```mpremote```

Run file on the badge

```
mpremote run file.py
```

Copy file from current folder to the badge

```
mpremote cp file.py :
```

Copy file from the badge to current folder

```
mpremote cp :main.py .
```

Mount current folder on the badge

```
mpremote mount .
```

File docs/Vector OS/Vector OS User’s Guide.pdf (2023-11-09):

# VectorOS User’s Guide

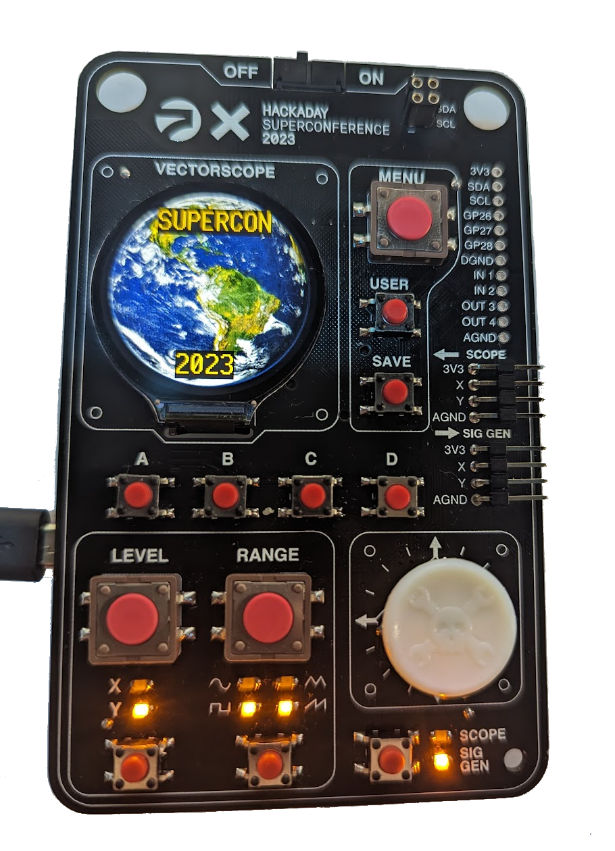
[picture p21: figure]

VectorOS User’s Guide v1.01 | 1

# Table of Contents

## Introduction

The Hackaday 2023 Supercon Badge has a sophisticated Raspberry Pi Pico RP2040 running MicroPython along with some sweet analog hardware. What will you do with it? To simplify your hacking, we’ve provided some example programs that use a simple framework called VectorOS.

VectorOS lets you cooperatively multitask (using MicroPython’s asyncio library). It also allows you to read the keyboard, set the LEDs, and draw on the screen. There’s a system to easily create menus as well. You can also set timers for one shot or repetitive timed tasks.

Creating a program using VectorOS involves a few steps:
- Configure VectorOS to know about your program
- Provide an entry point for the OS to run your code
- Use services and data provided by the OS
- Be sure your code yields to other tasks regularly

In addition, you can create “slots” that generate analog signals and then, with the help of some external wires, show them on the oscilloscope screen.

Important Note

Some of the files mentioned in this document are not on your badge or may be slightly out of date. Check the GitHub for the latest versions or if there are files mentioned herein that you don’t see on your badge. (https://github.com/Hack-a-Day/Vectorscope)

## Quick Start

If you want to jump right in, grab a copy of template.py from GitHub. Copy it to your Badge and edit it (we suggest mpremote (https://docs.micropython.org/en/latest/reference/mpremote.html) or Thonny (https://thonny.org/) to talk to the Badge). The comments in the example code (see GitHub; https://github.com/Hack-a-Day/Vectorscope) and some browsing should allow you to get something running quickly. If you didn’t read the configuration section below, you should do that now. It’s short, we promise. If you want to make oscilloscope traces, you might want to do a quick skim of Working with Waveforms, also below. Be sure to check out template.py for full programs and template_slot.py for waveforms, too.

If you want to configure what programs VectorOS can run, look in vos_launch.py. The menus are in menudemo.py.

Once you’ve had a taste, you can return here and get the details about how VectorOS can best help you work with the screen, keyboard, menus, and timers. It also manages starting your programs in the right environment.

## Configuration (vos_launch.py)

You configure your VectorOS setup by changing the file vos_launch.py. Note that all the items here are strings or numbers. Don’t use class names or import any packages in this file. Here are the things you must set:

Items in vos_launch.py

Item | Description
launch_list={ “key1”: “command1”, “key2”: “command2”,...} | Keys that refer to modules for launchable programs
auto_launch_list=[ “key1”, “key2”, …] | Keys from launch_list to launch on startup
auto_launch_repl=True | True to launch the onboard repl (to exit it, enter these command from the repl: Import sys sys.exit()
key_scan_rate=100 | Milliseconds to scan keys. Zero if you don’t want VectorOS to manage the keyboard scanning
gc_thread_rate=1200 | Milliseconds between garbage collection. Set to zero for default garbage collection or to manage it yourself (see also, vos_state.gc_suspend)
debug_level=DEBUG_LEVEL_SEVERE | The vos_debug.debug_print function will only output messages marked at the indicated level or lower. Common values (defined in vos_debug) are: DEBUG_LEVEL_SILENT -1 DEBUG_LEVEL_SEVERE 0 DEBUG_LEVEL_ERROR 10 DEBUG_LEVEL_WARNING 20 DEBUG_LEVEL_INFO 30

You do not execute this file, but you should execute vectoros.run() (you can call it from main.py, if you like, but probably should not call it from boot.py). If you want to be able to “execute” this file, you can add this to the bottom:

if __name__=="__main__":
import vectoros
vectoros.run()

Here’s an example file that loads several examples and runs menu and blinky on startup:

# list of things to launch from vectoros

# dictionary of tags to imports (will look for .vos_main() or .main()) launch_list={ "menu": "menudemo", "blinky": "blinker", 'sketch': 'sketch', "screen": "screentest"}

# list what you want to start auto (maybe just one thing?) need tag auto_launch_list=["menu", "blinky"]

auto_launch_repl=True

key_scan_rate = 100 # how often to scan the keyboard globally (ms; 0 to do it yourself)

# how often to garbage collect

# if you set this to zero and do nothing else

# garbage collection will be automatic as usual and before new tasks launch gc_thread_rate = 1200

# Base rate for the timer (ms)

timer_base_rate=100

# Debug level (messages must be < this level to print)

# That is, at level 0 only level 0 messages print

# at level 1 then level 1 and level 0 messages print

# Set level to -1 to stop all messages (assuming you only call debug_print with positive values)

# if you want to use symbols for debug level, these are defined in vos_debug:

DEBUG_LEVEL_SILENT=-1

DEBUG_LEVEL_SEVERE=0
DEBUG_LEVEL_ERROR=10
DEBUG_LEVEL_WARNING=20
DEBUG_LEVEL_INFO=30

debug_level=DEBUG_LEVEL_SEVERE

if __name__=="__main__":
import vectoros
vectoros.run()

### Structure of a VectorOS Program

Typically, a VectorOS program will contain, at least, an async vos_main() function which will be called at startup. You can make the function synchronous (that is, leave off the async), but this can cause memory leaks and other problems. If there is no vos_main() function, the OS will attempt to load your main() function. Again, this can be synchronous or asynchronous, but if it is your actual entry point, you should prefer async.

By convention, the vos_main() function will be your asynchronous entry point, and then you can use main as the synchronous entry point for cases where you want to run without the OS (e.g., for testing). The main can start up any support you need (like the timer or keyboard loop) and then launch vos_main() using asyncio.run. It is possible for VectorOS to launch a synchronous main or vos_main, but it is generally unreliable. Try to use an async function if at all possible.

Programs can use at least two different techniques. It is possible to have vos_main (or something it calls) loop forever, but use an asyncio.sleep() (or sleep_ms()) call to allow other tasks time to run (see the template below). You can also set up keyboard and timer callbacks and then just loop and pause forever (see the program simple.py in the examples section). You can also, of course, do both.

It is a good idea to allow a way for other programs to pause and exit your main loop. When exiting, clean up your entry in the task table with vectoros.remove_task(). The basic template (template.py) shows all of these techniques:

1) Synchronous main
2) Async vos_main
3) Launching the keyboard loop when not using VectorOS
4) Pausing and exiting the main loop
5) Removal of the task on exit

# Use this template to start your VectorOS program:

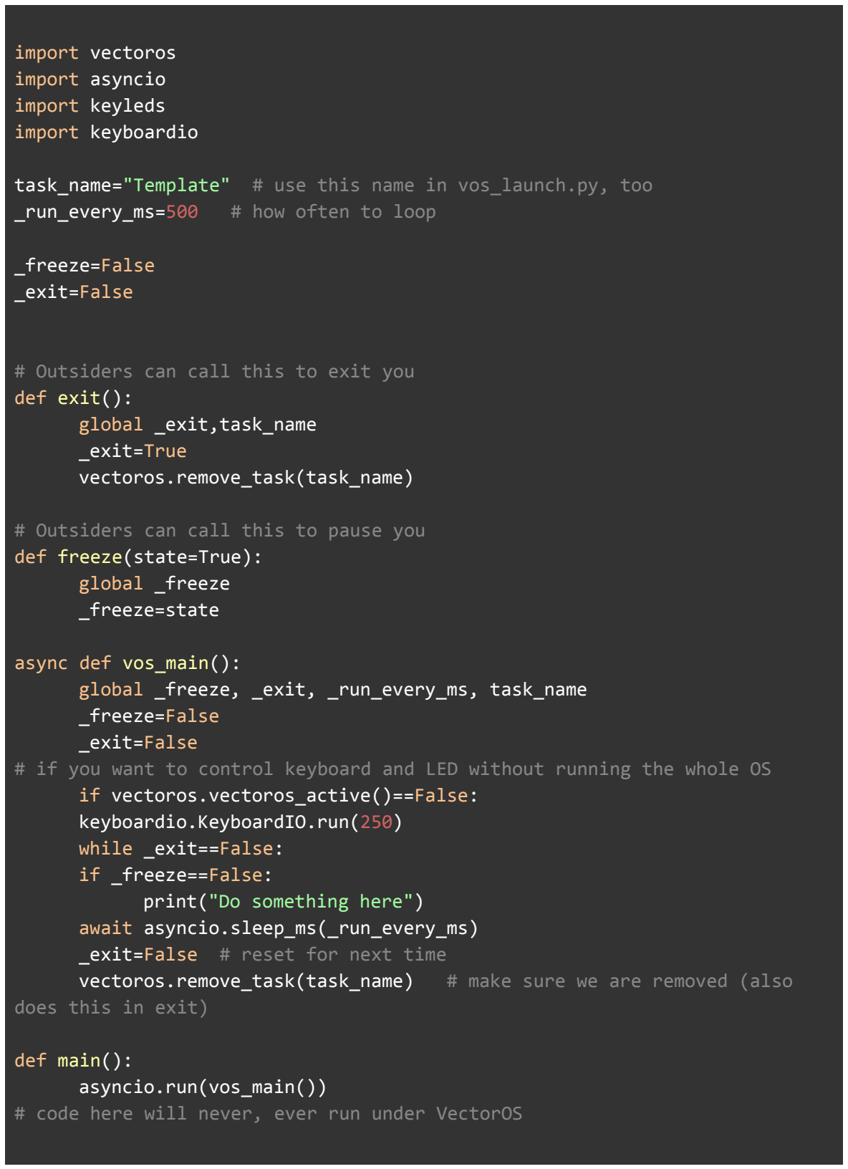
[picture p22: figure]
import vectoros import asyncio import keyleds import keyboardio; _run_every_ms=500; # how often to loop; _freeze=False _exit=False; # Outsiders can call this to exit you def exit(): global _exit,task_name _exit=True vectoros.remove_task(task_name); # Outsiders can call this to pause you def freeze(state=True): global _freeze _freeze=state; async def vos_main():; if vectoros.vectoros_active()==False: keyboardio.KeyboardIO.run(250) while _exit==False: if _freeze==False: print("Do something here") await asyncio.sleep_ms(_run_every_ms) _exit=False # reset for next time; does this in exit); def main(): asyncio.run(vos_main())

task_name="Template" # use this name in vos_launch.py, too

global _freeze, _exit, _run_every_ms, task_name

# if you want to control keyboard and LED without running the whole OS

vectoros.remove_task(task_name) # make sure we are removed (also

# code here will never, ever run under VectorOS

# if you want the possibility to run directly without VectorOS #if __name__=="__main__":

# main()

# if you want to configure to run in vos_launch but still run this file # add the main function to to vos_launch.py and use this:

if __name__=="__main__":
| vectoros.run()

In addition, there is code at the bottom that, if uncommented, would allow you to run without VectorOS. However, the code that is uncommented has a different purpose. It allows you to run this file and start VectorOS. If this program isn’t configured to automatically launch, that won’t actually run the program.

In summary, each program VectorOS knows about is configured in vos_launch. Programs can be launched automatically or by programs using, for example, a menu or button callback. In addition to normal programs, there are also Vectorscope slots that generate analog signals and displays them. These can be launched from buttons A, B, C, D, or under program control. When slots are running VectorOS releases the screen, stops managing garbage collection, and the Vectorscope component controls the system.

## Tutorial

Want to write Hello World for the badge? Here’s the steps we’ll take.
1. Create a program using template.py
2. Add our program to the list of programs in vos_launch.py
3. Add a menu item to launch our program.

We will assume you know how to use MicroPython using Thonny or mpremote. If not, maybe watch a YouTube before you get started. The tutorial program will show the word “Hello” on the screen and then count up periodically. You’ll press the Menu button to exit. Code you need to change or modify will be marked with a sticky note.

### Step 1. Create Program

Create a file called hello.py and copy the contents of template.py into it. Change the task_name variable near the top of the file to contain hello instead of Template. Be sure hello is all lower case. You can change the update rate in _run_ever_ms if you like (500 is a half second). You’ll notice there are imports for some VectorOS services already present. The top portion of the file should look like this:

# Use this template to start your VectorOS program:

import vectoros
import asyncio
import keyleds
import keyboardcb
import timer
from vos_state import vos_state
task_name="hello" # use this name in vos_launch.py, too | ADD THIS LINE
_run_every_ms=500 # how often to loop | OPTIONAL: CHANGE IF YOU LIKE

There are several global variables already defined:

_freeze=False
_exit=False
_menu_key=None

These variables are important:
- _freeze - if True, the main loop will continue but not do anything
- _exit - if True, the main loop will exit and the program will end, returning to the main menu
- _menu_key - This will hold the keyboard handler for the Menu key which needs to be shut down when the program exits

There are associated functions exit() and freeze() that set their respective variables and, in the case of exit() cleans up anything necessary.

Next is the vos_main() function, which is the normal entry point for the program. The line responsible for calling exit is there:

_menu_key=keyboardcb.KeyboardCB({keyleds.KEY_MENU: exit})

Note that the function has a dictionary with one entry in it. If you wanted to handle more keys, you could simply add their names (from keyless) to the dictionary and then provide a callback name. You can have a single callback for each key, or point multiple keys at the same callback function.

In addition, you can add new keyboard handlers if you prefer. For example, you might want a different handler that allows keys to repeat or that knows how to combine multiple keys from the joystick into one synthetic key (e.g., JOY_N and JOY_E to JOY_NE). The keyboard handler here does not repeat at all. It is not uncommon to have multiple keyboard or joystick objects in a single program. However, be sure to clean up all the keyboard objects before you exit. The template does this is the exit() function, although you can also use Python context management to make this more automatic, if you like.

This will cause the menu_key function to run when you press Menu. The program loops every half second. Find the line that says:

print("Do something here")

Replace that line with:

hello() | # this replaces the print statement

Now we need two functions: hello and menu_key. Put these above vos_main:

count=0 | # Add this entire block of code above vos_main

def hello():
global count
screen=vectoros.get_screen() screen.clear(0)
screen.text(40,120,f"Hello {count}!") count+=1
# End of block to add

Some of the code in the template allows you to run without VectorOS for testing purposes. If you want to make the file directly executable, you can uncomment the code at the bottom and comment out the existing code that runs VectorOS instead. We suggest not making any of the changes below. That way when you run your program, VectorOS will start (this is the default). However, during development, it can be useful to just run the program and this is how you do it.

# if you want the possibility to run directly without VectorOS

#if __name__=="__main__": # uncomment these two lines to run stand-alone

# main()

# changes here are optional – recommend to leave it as is

# if you want to configure to run in vos_launch but still run this file # add the main function to to vos_launch.py and use this:

if __name__=="__main__": | # If you uncomment above comment these two
vectoros.run()

Note that the template has special code that allows the keyboard, joystick, and timers to work without VectorOS started and some VectorOS services are not available like this, so in many cases, you are just as well off leaving it as the default. This program, however, will work either way. Even if you didn’t change the comments, you can always run your program from the MicroPython repl. Just type:

import hello

hello.main()

This assumes that your program doesn’t require VectorOS running. If it does, you may be able to start it from the built-in repl (turn it on in the Advanced menu). Or, you may have to complete the next steps and test in the full environment. For this program, though, it should work fine.

If it doesn’t work, you can use print statements to trace what’s going on. Once it works, you are ready to go to step 2, telling VectorOS how to find your program.

### Step 2. Configuring VectorOS

This is very simple. Open up vos_launch.py. Inside there is a dictionary called launch_list. Add an entry with your program’s identifier (hello; the same one we used in task_name) and the module name (in this case, hello). The line should look something like this (you may have different programs; the key is to add the “hello” item there. :

launch_list={ "menu": "menudemo", "blinky": "blinker", 'sketch': 'sketch', "screen": "screentest", "demo": "examples", "hello": "hello"}

### Step 3. Launch!

Your other programs can run your new program, but it is handy to link it to a menu item. The menu is controlled by a file called menudemo.py. Open it up and you’ll see several variables that hold the main menu and submenus.

Some menus dynamically change and that means the software needs to be able to find those items. That means inserting a menu item before a dynamic menu item may require further changes. For example, in the default main menu, the Blinker menu item changes to say Start Blinker or Stop Blinker. So as not to interfere with that, we’ll put our Hello item just below that item. Here’s what your main menu in menudemo.py should look like:

mainmenu=[["Demo",run_demo,None],
["Sketch", runsketch, 0],
["Badge", runbadge, 0],
["??? Blinker",blinkrun,(0,amenu)], # Note this must be in this position or you will have to change menu_custom above ["Hello",hellorun,0],
["GFX",gfxdemo,0 ],

["Freeze",freeze,0,"async"], ["Advanced>",SUBMENU,submenu]]

This tells the menu system to display the word Hello and when you select it to run the hellorun function which we need to write. The argument will receive a zero as an argument, but we won’t use it anyway. Here’s the function:

def hellorun(arg): | # enter this OR use the next box
vos_state.show_menu=False
vectoros.launch_task('hello')
return EXIT

However, you can also use the launch keyword instead. Then you don’t need hellorun at all. If you want to do it that way, go back to the mainmenu definition line and change the Hello entry like this:

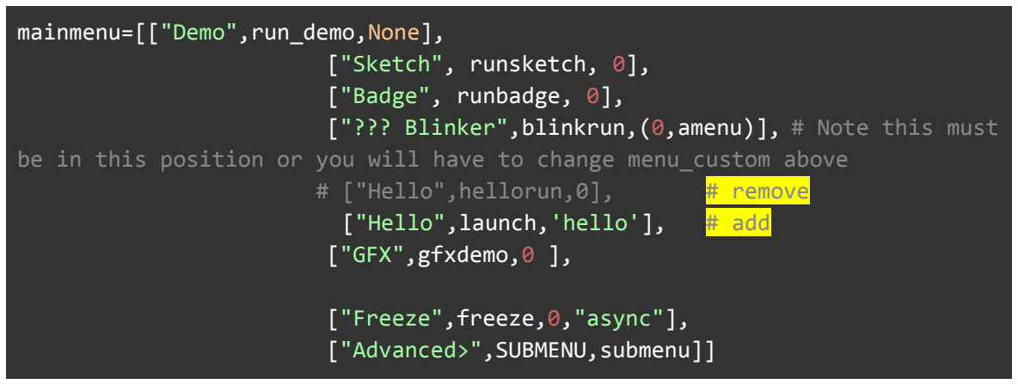
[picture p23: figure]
mainmenu=[["Demo",run_demo,None], ["Sketch", runsketch, 0], ["Badge", runbadge, 0],; # ["Hello",hellorun,0],; # remove; ["Hello",launch,'hello'],; # add; ["GFX",gfxdemo,0 ],; ["Freeze",freeze,0,"async"], ["Advanced>",SUBMENU,submenu]]

["??? Blinker",blinkrun,(0,amenu)], # Note this must be in this position or you will have to change menu_custom above

Now run vectoros.py or any program (like menudemo.py) that is configured to start VectorOS. You can select your program from the menu and watch it run. Press Menu when you want to exit.

### What’s Next?

You did it! You wrote a program that runs on the Vectorscope badge! This kind of looping program is common although you can also set up a program to run with timers. VectorOS starts the timer system automatically, but if you want to run independently, you’d need to start the timers just like this program started the keyboard loop (with run) if it detected that VectorOS wasn’t active.

If you want to get started writing Vectorscope waveforms, see Working with Waveforms, below.

## VectorOS Services

There are several VectorOS services available to programs. The sleep_for_ever and sleep methods are special cases. If they are called from code that is already in asynchronous mode, they may hang. For asynchronous code, you can use await asyncio.sleep() or asyncio.sleep_ms() in async methods. For more information about asynchronous programming, see the AsyncIO section below.

VectorOS Simple API (vectoros.py)

Call | Description
sleep_for_ever() | Sleep forever
sleep(n) | Sleep for n milliseconds
reset() | Hard reset the badge
soft_reset() | Soft reset the badge (keep connection to IDE; does not restart VectorOS)

These services are also available to programs:

VectorOS Normal API (vectoros.py)

Call/Variable | Description
get_screen() | Returns a ScreenNorm object for use to access the screen
vectoros_active() | Returns true if VectorOS is running and ready
launch_repl() | Launch the repl (assumes it isn’t already running). You normally won’t call this directly, but let vos_launch.py do it for you
launch(task_tag) | Launch a program by its tag defined in vos_launch.py
remove_task(task_tag) | Remove a task from the list by its tag. This does not stop or unload the task. It simply removes it from the list
launch_vecslot(slot) | Launch a Vectorscope routine by slot defined in vos_launch. Note that SlotX where X is A, B, C, or D will cause the slot to launch from the A, B, C, or D button.
vos_debug.debug_print(level,...) | Print (as a normal print) if debug_level in vos_launch.py is <= level
vectoros_startup(autolaunch=True) | Start up service and (optionally) autolaunch programs. Normally called automatically
vectoros_shutdown(deactivate | Attempt to shut down VectorOS services and

Call/Variable | Description
=True) | programs. If deactivate is False, don’t signal other programs via vos_state that we are shutdown
ext_run(cmd) | Shutdown VectorOS and run an “external program.” For example: ext_run(“import foo\nfoo.main”)

### Working with the Debug Level

In vos_launch.py, you can set a debug level. Then, in your code, you can import vos_debug and use vos_debug.debug_print() with a level to output different messages. Each call to debug_print() has an associated level that must be less than or equal to the level set in vos_launch.

Here are a few examples:

import vos_debug
vos_debug.debug_print(vos_debug.DEBUG_LEVEL_ERROR,
"Error",v,"is greater than 10!")

The levels are simple numbers and should be positive. However, there are some predefined levels:
- DEBUG_LEVEL_SEVERE 0
- DEBUG_LEVEL_ERROR 10
- DEBUG_LEVEL_WARNING 20
- DEBUG_LEVEL_INFO 30

In addition, DEBUG_LEVEL_SILENT is equal to -1 which will suppress all debug messages if set in vos_launch. This assumes, of course, that you never tag messages with a negative level.

If you have the REPL set to run, you can manipulate the debug level at run time by importing vos_launch and setting or reading vos_launch.debug_level directly.

## VectorOS State

The vos_state import provides a vos_state data structure that contains some variables about the state of VectorOS. The easiest way to use this structure is to include:

from vos_state import vos_state
print(vos_state.task_dict) # for example

VectorOS State (vos_state.py)

Field | Description
task_dict={} | Dictionary of tags and task objects. If a task exits, this isn’t updated automatically. In addition, $gc, $key, $timer, and $repl are system tasks, if so configured
gc_suspend=True | Suspend garbage collection
show_menu=True | Use this flag to activate the main menu (menudemo)
active | Returns True if VectorOS is running (also use vectoros.vectoros_active()
version | A unique version number

The vos_state.py file is a handy place (but not the only place) to put global variables you need. We suggest adding a single list or dictionary there to allow all programs to access variables with a separate name. For example, if your application is called SoundMachine, you might define:

sound_machine_data = { "option1": 0, "timeout": 30}

Then any file that wants to use this can write:

from vos_state import sound_machine_data print(sound_machine_data["timeout"]

## Working with the Keyboard, Joystick, and LEDs

The keyboardio.KeyboardIO object manages a single polling loop for the keys, including the joystick. You configure it to run as a task automatically in your VectorOS configuration, or you can do it manually. To use the keyboard, you normally will use keyboardcb.KeyboardCB or joystick.Joystick to set up callbacks to things you are interested in. You can also derive custom classes from KeyboardIO or any of the other keyboard classes. The class also manages the LEDs on the board. Key and LED definitions are in keyleds.py.

The classes are context managers, so you can use “with” to monitor their lifetimes. If you don’t, it is important that they don’t go out of scope, or that you call detach() when you are done so they stop getting keyboard events. See https://docs.python.org/3/reference/compound_stmts.html#the-with-statement for more details about context management.

Note that it is permissible to have multiple classes process keyboard events. For example, you might have a Joystick object with the direction keys set to repeat. You might also define a

KeyboardCB object that only handles the joystick press event in a non-repeat mode (and, perhaps, then, you don’t handle it in the Joystick object).

### KeyboardIO features

Initializing has an optional boolean flag. If True, the default, the instance will subscribe to keyboard events. If not, the object is made but will not be subscribed (use attach() later to subscribe). Note that all of these items are available in subclasses like KeyboardCB and Joystick. You will rarely use this class yourself unless you subclass it. You’ll usually use one of the built-in subclasses.

KeyboardIO API (keyboardio.py)

Call/Variables | Description
KeyboardIO(attach=True) | Constructor. If attach is false, the instance won’t process keyboard events
leds=0 | Class variable. Set this to influence the LEDs (see keyleds.py for definitions)
task=None | Class variable. Task ID for the keyboard polling task
current_keys=[] | Class variable. Used only in keyboard callbacks. Has a list of keys pressed. This can be useful to check for multiple keys being pressed at once
run(timeout=100) | Class method. Start the main loop with the specified millisecond timeout. Set to zero to use the default (100ms) or omit the argument. You usually won’t call this, but will set the timeout in vos_launch.py
attach() | Begin receiving keyboard events
detach() | Stop receiving keyboard events
capture(tf=True) | Prevent other keyboard objects from receiving keyboard events while the capture is active. Use False to release the capture. Returns false if the keyboard is already captured by someone else
key(buttons) | You don’t call this directly, but you can override it in a subclass to receive all keyboard events

### KeyboardCB Features

When you initialize a KeyboardCB object, you pass a callback. Callbacks can be in two forms: a function that gets all keys of interest (explained in a moment) or a dictionary of key IDs (from keyleds.py) and functions that take an argument telling you what key was pressed. The second parameter is a filter list of keys you are interested in. If this is present, you will only get these keys in your callbacks, even if you have a dictionary with more keys. However, if you don’t provide a filter list but you do provide a dictionary, the filter will be the dictionary’s keys. If you don’t provide either, your callback will get all keyboard events.

The last parameter to the constructor is a Boolean that is True by default. When True, this sets single key mode. In this mode, you will get one event for each key press. If this is false, then you will get multiple events as long as the key is pressed.

There is an active flag that stops all key processing in the object if it is True. There is also a set_callback method if you want to change the callback after construction.

The module has a non-class function called replace_chord. It takes a list of keys, a list of chord keys (that is, multiple key presses that should appear as one key), and a value to replace the chord with. This would be useful in a subclass that overrides key. For example, suppose you want to know if keyleds.KEY_A and keyleds. KEY_B are both set at the same time. The key vector might be [ KEY_A, KEY_SAVE, KEY_B ]. You could look for the key chord [KEY_A, KEY_B] and replace it with KEY_AB (which you would have to define). The resulting list would be [KEY_SAVE,KEY_AB].

KeyboardCB API (keyboardcb.py)

Call/Variables | Description
KeyboardCB(callback={}, filter=[], single_key_mode=True, attach=True) | Constructor. The callback can be a single function or a dictionary that maps keynames to functions. In either case, the functions take an argument that will receive the key name from keyleds.py.
| If filter is provided (a list of keys from keyleds.py), only those keys will be passed to the constructor. If there is no filter, but the constructor is a dictionary, the keys of the dictionary will be used as a filter. If neither apply, then the callback will get all keyboard events (assuming you don’t override the key function).
| The single_key parameter, if True, causes the callback to fire once per key press. If False, the callback is called at each scan period if the corresponding key is pressed.
| If attach is false, the instance won’t process keyboard events
set_callback(func_or_dict) | If you don’t specify a callback or you want to replace the existing one, you can use this call
keyboardcb.replace_chord(b, chord, value) | This is not a class method. It is useful in key() callbacks to search for multiple keys and replace them with a different key code. If b is the list of buttons pressed, chord is a list

Call/Variables | Description
| of keys to find (e.g., [JOY_UP, JOY_RIGHT] and value is the keycode to replace them with (e.g., JOY_NE). The search keys don’t have to be adjacent or in order in the list
active | Set to False to temporarily stop processing

### The KeyboardRepeat Class

The KeyboardRepeat class is exactly the same as the KeyboardCB class but allows keys to repeat slower than the scan rate. This is useful if you need a fast scan rate for some keys (e.g., the joystick) or to update LEDs quickly, but don’t want a fast repeat on other keys. Note that if you don’t mind keys repeating at the natural rate or you don’t want to repeat at all, you can simply use KeyboardCB.

KeyboardRepeat API (keyboardrepeat.py)

Call | Description
KeyboardRepeat(repeat_count=3, callback={}, filter=[], attach=True) | Constructor. The callback is the same as KeyboardCB, other than you specify a repeat count and you can’t ask for single key mode. The callbacks will fire when you first press the key and then repeat after the number of scans indicated

### The Joystick Class

The Joystick class is exactly the same as the KeyboardCB class, but you only provide a callback and, optionally, if you want single keys or not (default is False, get repeat keys).

The result is the same as using the KeyboardCB, but it also synthesizes chords like KEY_NE for a northeast joystick press. These are defined in keyleds.py.

Joystick API (joystick.py)

Call | Description
Joystick(callback={}, single_key_mode=False, attach=True) | Constructor. The callback is the same as KeyboardCB, and the filter is automatically set to JOY_ALL. The single_key_mode and attach parameters are the same as in KeyboardCB

### A Demo of the Keyboard Classes

The following program is not a VectorOS program, although it does use the sleep_forever call from VectorOS. Pressing certain keys will print messages on the terminal to illustrate various features of the keyboard system.

The callbacks here are all local to the main() function, but this does not have to be the case. Note that after defining callbacks, the demo spins up a keyboard polling task using keyboardio.KeyboardIO.run(50) so the scan rate is approximately 50 milliseconds.

There are 6 different keyboard handlers in this code, each showing off different aspects of the system:
- debugkey - Print messages for key A, B, C, and D. This uses a filter and a single callback
- cb1 - Watch for the SAVE key. The callback can distinguish between SAVE and SAVE+A being pressed.
- cb2 - Also print messages for key A, B, C, and D using a dictionary callback and filter. If you press D, the debugkey handler will be detached. Pressing A will reattach it.
- joy - This handles the joystick. It also shows how a lambda can be used as a callback.
- rpt - Monitor the RANGE key with a slow repeat rate (50x20 is about 1 second).
- fast - Monitor the LEVEL key with a natural repeat rate (50 milliseconds)

import keyleds
import keyboardio
import keyboardcb
import keyboardrepeat
import joystick
from vectoros import sleep_forever

# This demo does not handle all keys (but it could) # it does handle

# 1 - A, B, C, D with a generic catch all callback

# 2 - A, B, C, D with separate callbacks

# 3 - Save and A+Save

# 4 - The Joystick including synthetic corner directions # 5 - Range button on a 1 second repeat

# 6 - Level button on a 50ms repeat

if __name__ == "__main__":

def main():

global debugkey
# stupid callback

def generic_cb(key):
print(f"Got {key}")
# example callback that is not in a class. It also detects the A modifier key

# you can also build classes to recognize chords like joystick does

def global_cb(key):
if keyleds.KEY_A in keyboardcb.KeyboardCB.current_keys: print("A+Save pressed")
else:
print("Global Save CB")
debugkey = None

def cba(key):
keyboardio.KeyboardIO.leds=keyleds.LED_X
print("A!")
debugkey.attach() # if we press A after D, reattach! def cbb(key):
print("B!")
keyboardio.KeyboardIO.leds=keyleds.LED_Y
def cbc(key):
print("C!")
def cbd(key):
print("D!")
debugkey.detach() # shut the other one up after pressing D def ranger(key):
if key==keyleds.KEY_RANGE:
print("Range repeats slowly!")
else:
print("Normal repeat")

# spin up the keyboard "server" which runs once keyboardio.KeyboardIO.run(50)

debugkey=keyboardcb.KeyboardCB(generic_cb,keyleds.KEY_ABCD) # watch ABCD with default callback cb1=keyboardcb.KeyboardCB(global_cb,keyleds.KEY_SAVE) # watch KEY_SAVE
# probably wouldn't do two different ones for same keys

# but wanted to show how to do individual callbacks -- you could build this dictionary on a different line and pass it

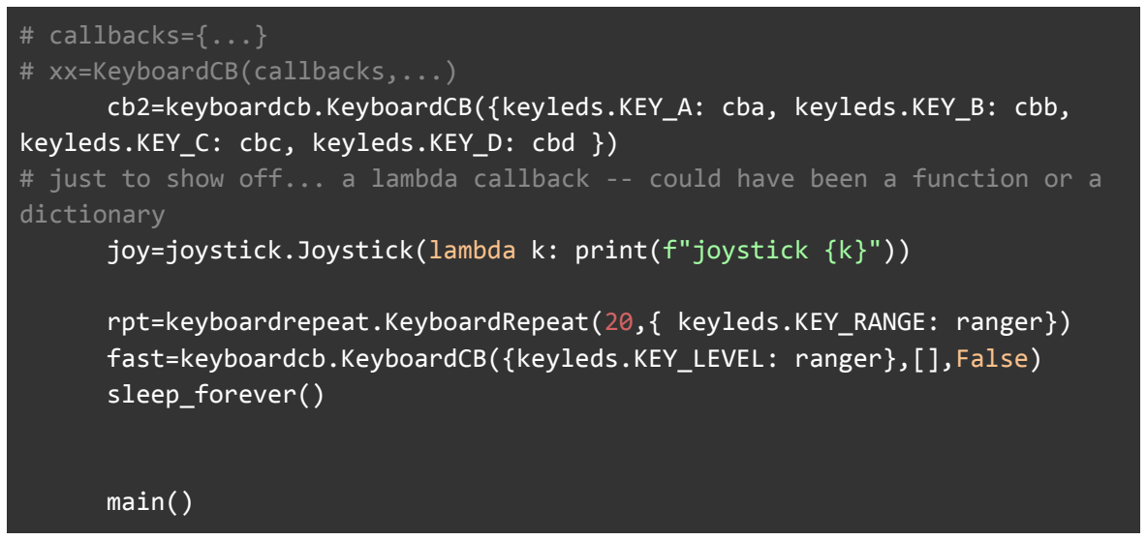
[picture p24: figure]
# callbacks={...} # xx=KeyboardCB(callbacks,...); dictionary; sleep_forever(); main()

cb2=keyboardcb.KeyboardCB({keyleds.KEY_A: cba, keyleds.KEY_B: cbb, keyleds.KEY_C: cbc, keyleds.KEY_D: cbd })
# just to show off... a lambda callback -- could have been a function or a

joy=joystick.Joystick(lambda k: print(f"joystick {k}"))

rpt=keyboardrepeat.KeyboardRepeat(20,{ keyleds.KEY_RANGE: ranger}) fast=keyboardcb.KeyboardCB({keyleds.KEY_LEVEL: ranger},[],False)

### Working with Multiple Key Presses

There are several ways to detect that multiple key presses have occurred at the same time (e.g., press A and move the joystick up). First, during a callback, KeyboardIO.current_keys contains a list of all keys currently pressed (regardless of your filter). So you can check to see if a key is down or not by testing for membership in the list. For example:

def global_cb(key):
if keyleds.KEY_A in keyboardcb.KeyboardCB.current_keys: print("A+Save pressed")
else:
print("Global Save CB")

In this case, KeyboardCB accesses the list, which is fine since it is a subclass of KeyboardIO and the current_keys belongs to the class, not a particular instance.

The second method is to create a subclass of another keyboard object. The Joystick class (see below) does this. The key() method receives a filtered list of keys, and you can find key combinations and replace them with equivalent key codes. Because this is so common, the keyboardcb module has a global-level function to do this.

The replace_chord method takes a list of keys, a list of chord keys (that is, multiple key presses that should appear as one key), and a value to replace the chord with. Here’s a portion of the code in joystick.py:

def key(self, b):
# generate synthetic keys

b1 = keyboardcb.replace_chord(b, [keyleds.JOY_N, keyleds.JOY_E],

keyleds.JOY_NE)
b1 = keyboardcb.replace_chord(b1, [keyleds.JOY_N, keyleds.JOY_W], keyleds.JOY_NW)
b1 = keyboardcb.replace_chord(b1, [keyleds.JOY_S, keyleds.JOY_E], keyleds.JOY_SE)
b1 = keyboardcb.replace_chord(b1, [keyleds.JOY_S, keyleds.JOY_W], keyleds.JOY_SW)

super().key(b1) # dispatch callbacks as usual

### Working with LEDs

The LEDs are not directly connected to the CPU I/O ports. They are connected to a shift register that is also used to scan the keys. Therefore, to use the LEDs, you must have a running keyboard task, which, if you are using VectorOS, you do. However, you can also use your own code to launch a keyboard loop (keyboardio.KeyboardIO.run).

KeyboardIO has a class variable called leds that reflects the state of the LEDs, and they are updated at the keyboard scan frequency. If you don’t mind writing to that byte value using the constants in keyless.py, then that’s all you need to do. However, if you would prefer a higher-level interface, you can use the LED objects defined in led.py. There are eight predefined objects that you can use to control each LED easily. You do not need to create instances or subclass LED. In fact, accessing the LEDs through derived classes will not work unless the derived class is the one running the event loop.

LED API (led.py)

Call/Property | Description
set() | Set (turn on) the LED
reset() | Reset (turn off) the LED
toggle() | Flip the LED from on to off or vice versa
value | A property. Set or read the LED state as a True/False or 1/0 (always reads True or False)

In addition to the above calls, the objects themselves are callable, which is the same as setting the value property. For example:

LED.Square(True) # Turn on square wave LED

The predefined LED objects are:
- X

- Y
- Triangle
- Square
- Sine
- Sig
- Scope
- Saw

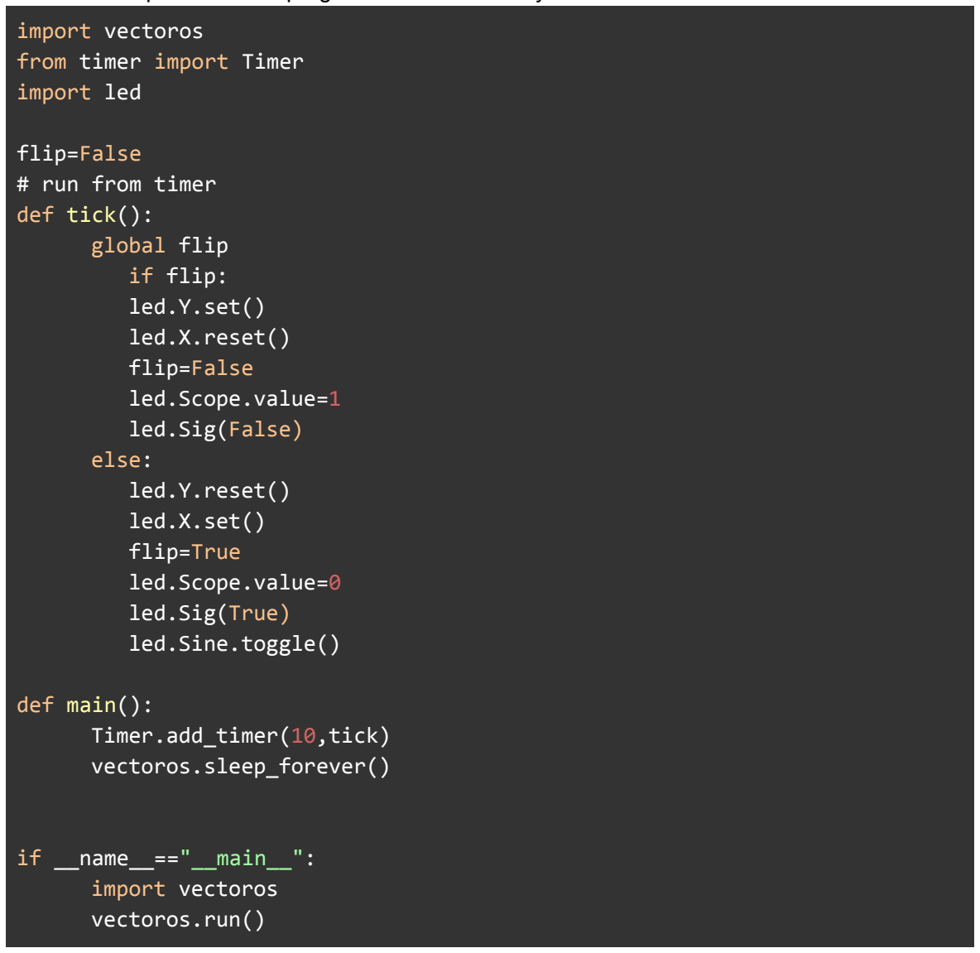
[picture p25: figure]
import vectoros from timer import Timer import led; flip=False # run from timer def tick(): global flip if flip: led.Y.set() led.X.reset() flip=False led.Scope.value=1 led.Sig(False) else: led.Y.reset() led.X.set() flip=True led.Scope.value=0 led.Sig(True) led.Sine.toggle(); def main(): Timer.add_timer(10,tick) vectoros.sleep_forever(); if __name__=="__main__": import vectoros vectoros.run()

Here is a sample VectorOS program that uses this style of interaction with the LEDs:

## Working with Timers

In addition to creating a loop that sleeps, you can also install a callback on a timer. The timer’s base rate is set in vos_launch (timer_base_rate) in milliseconds. All timeouts are computed against that base rate. The base rate should not be too fast (e.g., 10 milliseconds is probably too fast, and you will get recursion errors as the timer’s loop overruns itself). The default is 100 milliseconds.

You don’t have to instantiate the timer object. You only need to refer to Timer. VectorOS runs the timer loop as part of its startup (unless you set the base rate to zero). The only methods you normally deal with are add_timer and remove_timer. The add_timer call takes a number of ticks and a callback. There is also an argument to specify that the timer should fire only once or if it should repeat.

Because of the nature of asyncio, you can’t depend on these timers to be extremely accurate, and any time you spend processing synchronously may affect the accuracy of the timer. A synchronous callback needs to exit as soon as possible. Still, for many tasks, they work well. If you need more robust timing services, check out https://docs.micropython.org/en/latest/rp2/quickref.html#timers.

Note that the callback can be the name of a function (the default) or an “awaitable.” For example:

def cb1(): # sync callback
print("Tick")

async def cb2(): # async callback print("Tock")

tick_timer=timer.Timer.add_timer(100,cb1) tock_timer=timer.Timer.add_timer(100,cb2)

If you use an awaitable (e.g., an async function), the timer will call it with await. However, if needed, it can then create a new async task and return. In other words, either way, the timer will stall until the callback completes.

You can also create subclasses of the Timer object. The timer object is a context manager, so you can use “with” to ensure it doesn’t stay active when you are done with it, or you can
manage that yourself by ensuring timers are paused when you are done with them. Here’s a simple example of a custom Timer class:

class Test(Timer):
def __init__(self):
super().__init__(20)
self.ct=0

def action(self):
self.ct=self.ct+1
print("**",self.ct)
if (self.ct>=10):
self.pause()
At a base rate of 100ms, this timer will print “**1”, “**2”, etc. every two seconds until it reaches
10. Then, it will stop. To use it, you only have to write:

twosec=Test()

Or use a context manager:

with Test() as twosec:

Timer API (timer.py)

Call | Description
run() | Class method. Start the timer loop (usually not required with VectorOS)
baserate | Class variable. The base rate in milliseconds (usually not required to set when using VectorOS)
add_timer(ticks,callback, oneshot=False) | Class method. Add a timer callback which may be synchronous or asynchronous and occur once or repeat. Returns a timer ID
remove_timer(id) | Class method. Remove the specified timer ID
gc_delay | Class variable. Usually not needed with VectorOS. If this is set, then garbage collection will occur after the specified number of ticks inside the main timer loop
Timer(ticks, paused=False,oneshot=False) | Constructor. Create a timer that will call self.action as indicated
pause() | Pause this Timer instance
resume() | Start a paused timer or oneshot instance

Call | Description
action() | Override to add your code to a timer instance (do not call the base class)

## Working with the Screen

The screen isn’t really a VectorOS resource, but you can use the ScreenNorm object to control it. By default, the screen is awake, but you can put it to sleep with idle() or wake it up again with wake(). Since there only needs to be one ScreenNorm object, VectorOS provides get_screen() to return the screen instance. The screen has nominal dimensions of 240x240.

Screen API (screennorm.py)

Call/Variable | Description
ScreenNorm() | Constructor. No arguments. The screen starts in the awake state
tft | The underlying screen object (see https://github.com/russhughes/gc9a01_mpyhttps://github.com/russhughes/gc9a01_mpy) (https://github.com/russhughes/gc9a01_mpy)
idle() | Turn off the display and release the SPI bus
wake() | Turn on the display
jpg(filename) | Show a 240x240 JPG file (convenience wrapper for tft)
text(x,y,text,fg_color, bg_color) | Display text at location x,y in the given foreground and background colors (omit for default colors)
text_font(font, x, y, text, fg_color, scale=1.0) | Display text using vector font (as text). Always transparent. Use None for the default font or one of the fonts at https://github.com/russhughes/gc9a01_mpy/tree/main/fonts/vecto r (https://github.com/russhughes/gc9a01_mpy/tree/main/fonts/vector)
clear(color) | Clear the screen with the given RGB565 color (default black)
pixel(x,y,color) | Set pixel at x,y with given RGB565 color
get_font() | Get the default bitmap font
get_vfont() | Get the default vector font

### Screen Colors

The colors.py file has several colors you can use with the display, including those that mimic a green CRT.

Colors (colors.py)

Color/Call | Notes

BLACK, BLUE, CYAN, GRAY, GREEN, MAGENTA, RED, WHITE, YELLOW

PHOSPHOR[n] | Green CRT-style colors n=0 to 31
PHOSPHOR_BRIGHT | Highlight color
PHOSPHOR_DARK | Normal color
PHOSPHOR_BG | Background color
rgb(red, green, blue) | Convert a normal 8-bit per color RGB triple to a screen color

## Working with Menus

It is simple to create menu-driven user interfaces with the Menu class. You configure the menu with a nested list containing a sublist for each menu item. The sublist has the format: [ text, callback, argument ]. For example:

[[ "Item #1", item_process, 1],["Item #2", item_process, 2],
["Item #3", item_3,0]]

In this case, the item_process(arg) function would handle the first two menu items and item_3(arg) would handle the last one. You must call the menu from an async function using await:

with Menu(clear_after=True) as amenu: await amenu.do_menu(mainmenu)

The with statement allows the menu, which is a context manager, to release its internal keyboard handler when it goes out of scope. You can also manage this without using context management. You also have the ability to set a callback (or subclass menu) to dynamically set the menu based on current conditions.

To specify a submenu, use an action of [] (or Menu.SUBMENU) and provide the variable containing the submenu definition as the argument. If you use None as the action, the menu item will work as a back button.

Menu callbacks receive an argument from the configuration list. They are expected to return a value. Returning Menu.CONT allows the menu system to continue. Menu.BACK will do a back action. Menu.EXIT will exit the menu system.

Typically, callbacks are synchronous (non-async) functions. If you need an asynchronous call, just add an additional argument (we like “async” but anything will work) as the fourth item of the menu list.

[["My async Item",asynccb,0,"async"]....

A common thing to do is to launch a predefined VectorOS task (defined in vos_launch). You can do this by specifying menu.launch as the action of a menu item and use the tag string as an argument.

Menu System API (menu.py)

Call | Description
Menu(fg_color, bg_color, cursor_fg, cursor_bg, clear_after, joy_controller, scanrate) | Constructor. All arguments are optional. The fg and bg parameter sets colors. Set clear_after to True to have the menu system clear the screen on exit. The joy_controller argument sets a custom keyboard handler (you will rarely use this). Set scanrate to a non-zero to have the menu start a main keyboard task (never set this while using VectorOS). If cursor_fg or cursor_bg are None, they assume the value of the background and foreground, respectively
detach() | Stop responding to keyboard events
menu_custom() | Override this to have a chance to change the menu each time it is displayed. By default, it will call a callback for this purpose if you set one
set_callback(func) | The default menu_custom function calls the callback you set here before the menu draws or redraws
set_font(font,scale=1.0) | Set a vector font or None for the default font or “*” for the default vector font. The scale is a float and defaults to 1.0
menu_update() | Redraw menu
do_menu(menulist) | Execute menu
menu.launch(tag) | Global: turn off menus and launch a tag defined in

Call | Description
| vos_launch.py. Set vos_state.show_menu to True to turn menus back on later.

You often won’t need to customize the menu. However, if you need to dynamically change entries (for example, change an entry from On to Off depending on some external state) you can do it. To customize the menu you can override menu_custom or use set_callback to cause the default menu_custom to call you each time is about to draw the display. Here’s an example of a callback function:

# change menu[0][2] depending on state of blinky

def menu_custom(the_menu):
if the_menu.level==1:
if 'blinky' in vos_state.task_dict:
the_menu.current[2]=["Stop Blinker",blinkrun,(0,the_menu)] else:
the_menu.current[2]=["Start Blinker",blinkrun,(1,the_menu)]

The numbers here would change, of course, if you changed the structure of the menu. Setting the callback is simple:

with Menu(clear_after=True) as amenu: amenu.set_callback(menu_custom) await amenu.do_menu(mainmenu)

Note that, in this case, only the top-level menu changes (because of the test in menu_custom for the_menu.level). The callback function sets the altered menu item to have a callback that takes an argument composed of a number and a pointer to the menu because this item might want to read or alter things in the menu, too. You can write that function (in part) like this:

def blinkrun(arg):
flag, amenu = arg

### Menu List Reference

Menu items use a list to configure each item, and the menu itself is a list of lists. You can use the following items in a menu:

Menu List Reference

Action | Argument | Description
<function> | <argument> | Call function. Return MENU.BACK, MENU.EXIT, or (normally) MENU.CONT.
[] | Submenu list | Open submenu
Menu.SUBMENU | Submenu list | Open submenu
None | Ignored | Back (or exit from top level)
Menu.m_back | Ignored | Back (or exit from top level)
Menu.m_exit | Ignored | Exit menu
menu.launch | tag | Launch a tag after turning off menu

For example, you might have:

[["Program 1", run,1],["Program 2", run, 2],["Submenu"], [Menu.SUBMENU,menu_3],["Back",Menu.m_back,0]]

## About AsyncIO

Python allows cooperative multitasking via coroutines using the asyncio library. MicroPython provides a subset of asyncio with some extensions. VectorOS uses asyncio to allow you to run different parts of your code in a way so that it appears that it is all running at the same time.

By appears, we mean that the code doesn’t actually run at the same time. Rather, each piece of code (an asyncio task) runs until it has to stop for some reason. Then, another piece of code can run. This is simple and avoids many multitasking problems with critical sections. However, it means that a piece of code that refuses to stop will hang the entire system.

VectorOS tries to hide much of the complexity of asyncio. If you want, VectorOS can launch your code using a normal Python function. In some simple cases, that may be all you need. However, if you intend to do much of anything with other programs running, you’ll want to make your main function be async. Your main function should be named vos_main, although main is acceptable. By convention, main is a non-async entry point used when running code without the whole OS running. The template (template.py) sets this up for you:

async def vos_main():
global _freeze, _exit, _run_every_ms, task_name

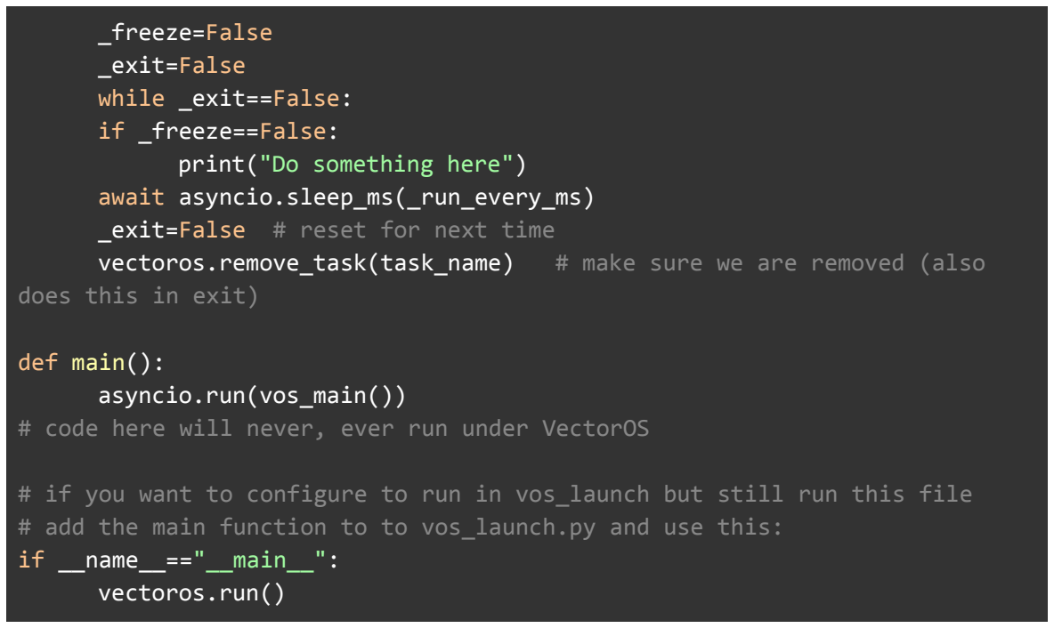
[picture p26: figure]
_freeze=False _exit=False while _exit==False: if _freeze==False: print("Do something here") await asyncio.sleep_ms(_run_every_ms) _exit=False # reset for next time; does this in exit); def main(): asyncio.run(vos_main()); if __name__=="__main__": vectoros.run()

vectoros.remove_task(task_name) # make sure we are removed (also

# code here will never, ever run under VectorOS

# if you want to configure to run in vos_launch but still run this file # add the main function to to vos_launch.py and use this:

Inside an async function, you can call normal functions, although they will, generally, prevent you from releasing time to other functions. You can also create tasks (asyncio.create_task) or call other async functions and wait for them using await.

Note that vos_main loops until it sees the _exit flag set. It regularly calls another async function: asyncio.sleep_ms to pause to let other things run.

For more about asyncio, see the References section below.

## Working with Waveforms

What good is a vectorscope if you can’t produce signals and watch them on the screen? Of course, you can.

There are several parts to creating a waveform display:
1) Write a file that provides a function slot_main that takes a single argument. That argument is a Vectorscope object. Use that object to produce your analog voltages for display on the screen. If you think you’ll want to use VectorOS services, you’ll wnat to make the function async.
2) Register the function with VectorOS by editing vos_launch.py. The entry must be in the vectorscope_slots dictionary. Slots named slotA, slotB, slotC, and slotD will run when you press the A, B, C, or D button from the menu screen.
3) If you want to launch some other way, you can call vectoros.launch_vecslot with the name of the slot.

4) When the routine finishes, the badge will reset.

You can think of Vectorscope as a driver that manages the oscilloscope display. The way to control this is through the wave member that provides a Waveform object. This uses a 256-sample buffer to drive X and Y voltage outputs on the SIG GEN pins. If you then feed the X and Y outputs to the badge’s SCOPE X and Y pins, you can draw anything you want. The members appear in the table above.

Waveform API (waveform.py)

Call/Variable | Description
outBuffer_ready | True when the out buffer is ready for new data
num_samples | Number of samples per frame
outBufferX | The X output buffer
outBufferY | The Y output buffer
packX(wavelist) | Put list of integers into X buffer
packY(wavelist) | Put list of integers into Y buffer
constantX(value) | Fill X buffer with integer
constantY(value) | Fill Y buffer with integer
point(x,y,value) | Fill buffer to produce a point

For example, here’s a simple “slot” example:

import math
import time

from vectorscope import Vectorscope from random_walk import RW

import vectoros
import keyboardcb
import keyleds
import asyncio

_abort=False

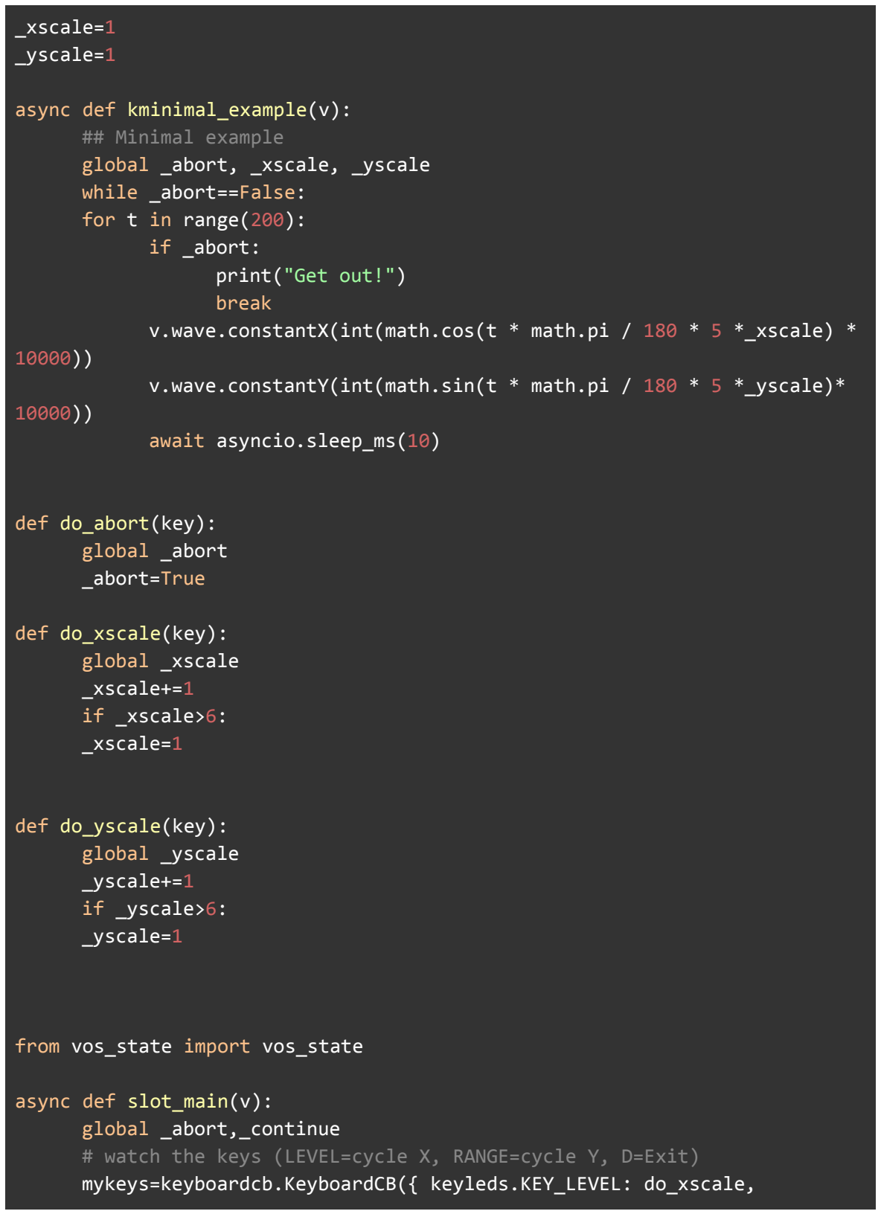
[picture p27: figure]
_xscale=1 _yscale=1; async def kminimal_example(v): ## Minimal example global _abort, _xscale, _yscale while _abort==False: for t in range(200): if _abort: print("Get out!") break; await asyncio.sleep_ms(10); def do_abort(key): global _abort _abort=True; def do_xscale(key): global _xscale _xscale+=1 if _xscale>6: _xscale=1; def do_yscale(key): global _yscale _yscale+=1 if _yscale>6: _yscale=1; from vos_state import vos_state; async def slot_main(v): global _abort,_continue

v.wave.constantX(int(math.cos(t * math.pi / 180 * 5 *_xscale) *

v.wave.constantY(int(math.sin(t * math.pi / 180 * 5 *_yscale)*

# watch the keys (LEVEL=cycle X, RANGE=cycle Y, D=Exit) mykeys=keyboardcb.KeyboardCB({ keyleds.KEY_LEVEL: do_xscale,

keyleds.KEY_RANGE: do_yscale, keyleds.KEY_D: do_abort}) await kminimal_example(v)
print("OK done")

The main loop uses the fact that you can describe a sine wave as:
A*sin(2πFt+Φ)
Where A is the amplitude, t is the time, F is the frequency in Hertz, and Φ is the phase angle in radians. The cos wave is the same, but phase shifted. Read more: https://en.wikipedia.org/wiki/Sine_wave.

The slot_main function sets up the keyboard using VectorOS and then calls the kminimal_example function. You can press the Level and Range buttons to change the X and Y frequencies between 1 and 6. Press D to exit.

Note that the scope display routine needs time to process, but if you are using VectorOS service (which you don’t have to), then the cooperative multitasking requires some pauses in your code. However, the bulk of the scope code runs on the Pico’s other core to minimize this issue. Still, you may have to plan your timing in your code correctly to allow VectorOS services to run and still have data for the scope.

When you are not running a slot, VectorOS provides garbage collection for you. When you are running a slot, the Vectorscope code does it for you. In addition, while running a slot, the VectorOS screen is unavailable.

You may find the file template_slot.py useful as a starting point for writing your own slots. You can also find a more complete example in the example code below.

### Inside generate_wavetables.py

You may find functions in generate_wavetables.py useful to create waveforms using degree measurements.

Function | Description
phaseSteps(maxphase, length=256) | Generate phase table
sine(maxPhase=360,length=256) | Sine wave
sawtooth(maxPhase=360, length=256) | Sawtooth
square(maxPhase=360, length=256) | Square
triangle(maxPhase=360, length=256) | Triangle
bandlimitedSawtooth(numberPartials, | Sawtooth with bandwidth limiting

maxPhase=360, length=256)

bandlimitedSquare(numberPartials, maxPhase=360, length=256) | Square with bandwidth limiting
bandlimiteTriangle(numberPartials, maxPhase=360, length=256) | Triangle with bandwidth limiting
scaleAndRound(data, scale=2**16-1, signedInt=True) | Scale samples

## Example Code

Example code is available on GitHub (https://github.com/Hack-a-Day/Vectorscope).. You can use the joystick to navigate the menus. Pushing the joystick or moving it to the right selects an item. Moving left goes back, as do some menu items marked “Previous.”

Some of the example applications include:
- Lissajous - Use the joystick keys to adjust frequency (left/right for X, up/down for Y). If you hold down RANGE while moving the joystick to control the amplitude. Hold down LEVEL to adjust phase with the joystick, although the code also periodically adjusts the phase. To change the waveform used, select X or Y with the bottom left buttons and then press the waveform button to cycle through sine, square, sawtooth, and triangle. Menu button exits.
- Sketch - Use the joystick to move the cursor. If the cursor is reddish, you’ll leave a trail in the current color. Push the joystick to toggle to move only mode (greenish cursor). The A, B, C, and D buttons select colors (black, red, green, blue). The Level button will change the color to white (erasing). The User button clears the screen. Menu will return to the menu. The most recent version allows you to press SAVE+A,B,C,D to save up to four screens for recall. Press User+A,B,C,D to recall.
- Planets - Show a graphic slide show of the planets (and the moon). The joystick can advance (right) or pause (left toggles). Use up and down to change the speed of the slide show. Menu exits.

You can also find a template for writing a simple VectorOS program in the template.py file (see below). It shows how you can set up the program to run virtually standalone for debugging or how you can set it to run and start up VectorOS.

# Use this template to start your VectorOS program:

import vectoros
import asyncio
import keyleds
import keyboardio

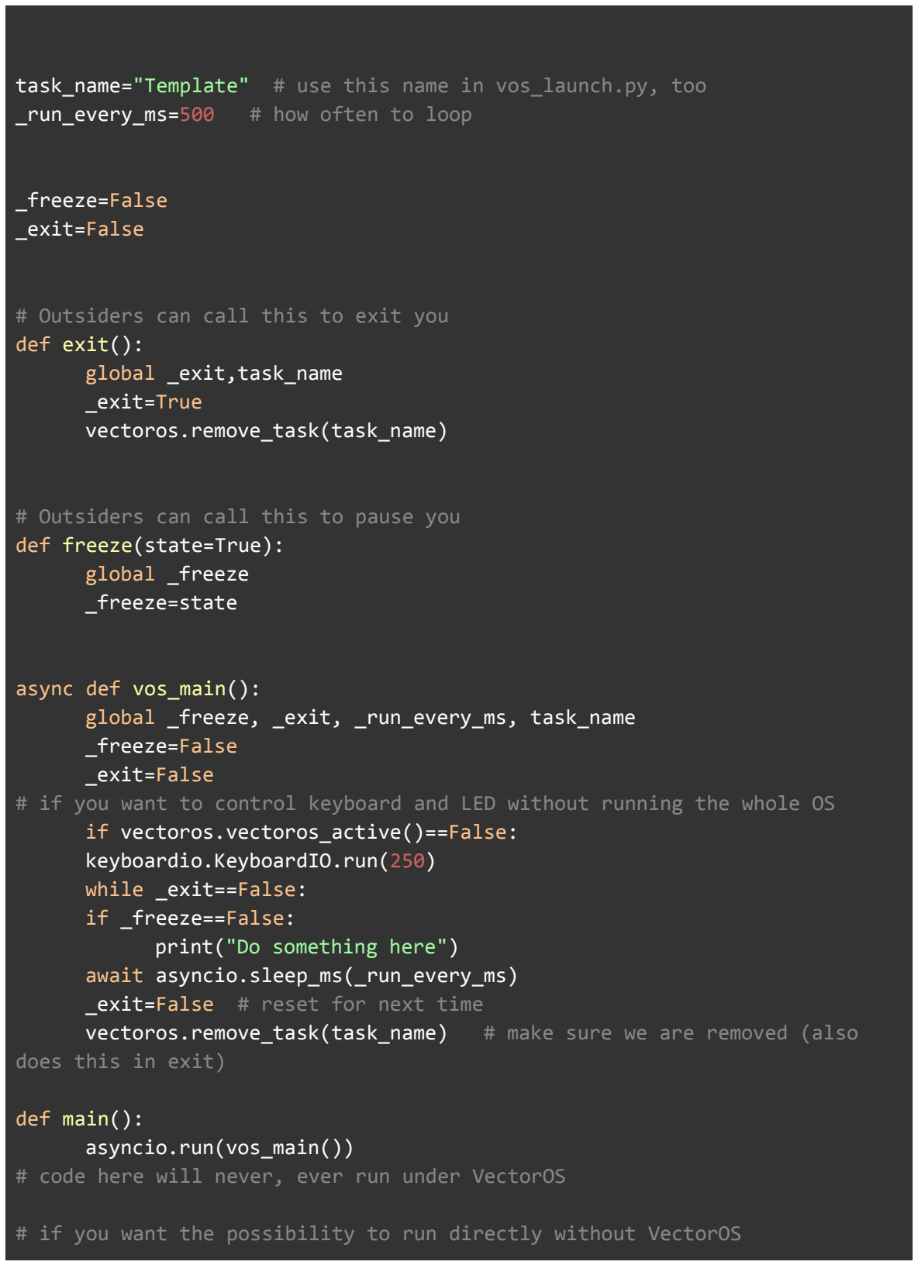
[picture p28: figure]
_run_every_ms=500; # how often to loop; _freeze=False _exit=False; # Outsiders can call this to exit you def exit(): global _exit,task_name _exit=True vectoros.remove_task(task_name); # Outsiders can call this to pause you def freeze(state=True): global _freeze _freeze=state; async def vos_main():; if vectoros.vectoros_active()==False: keyboardio.KeyboardIO.run(250) while _exit==False: if _freeze==False: print("Do something here") await asyncio.sleep_ms(_run_every_ms) _exit=False # reset for next time; does this in exit); def main(): asyncio.run(vos_main())

task_name="Template" # use this name in vos_launch.py, too

global _freeze, _exit, _run_every_ms, task_name

# if you want to control keyboard and LED without running the whole OS

vectoros.remove_task(task_name) # make sure we are removed (also

# code here will never, ever run under VectorOS

# if you want the possibility to run directly without VectorOS

#if __name__=="__main__":

# main()

# if you want to configure to run in vos_launch but still run this file # add the main function to to vos_launch.py and use this:

if __name__=="__main__":
| vectoros.run()

### Inside simple.py

By default, simple.py isn’t included in the demo. It is perhaps the least amount of code required to blink the LEDs in a VectorOS program. It starts with the template, but does not use any async calls at all. In truth, it could be a little less complex, but it does expose functions to allow you to pause and stop it.

Here’s the code:

# Almost the simplest VectorOS program:

import vectoros
import keyleds
import keyboardio
from timer import Timer

task_name="Simple" # use this name in vos_launch.py, too _run_every_ms=500 # how often to loop

_freeze=False
_exit=False
_timerid=None

# Outsiders can call this to exit you def exit():

global _exit,task_name
_exit=True
vectoros.remove_task(task_name)

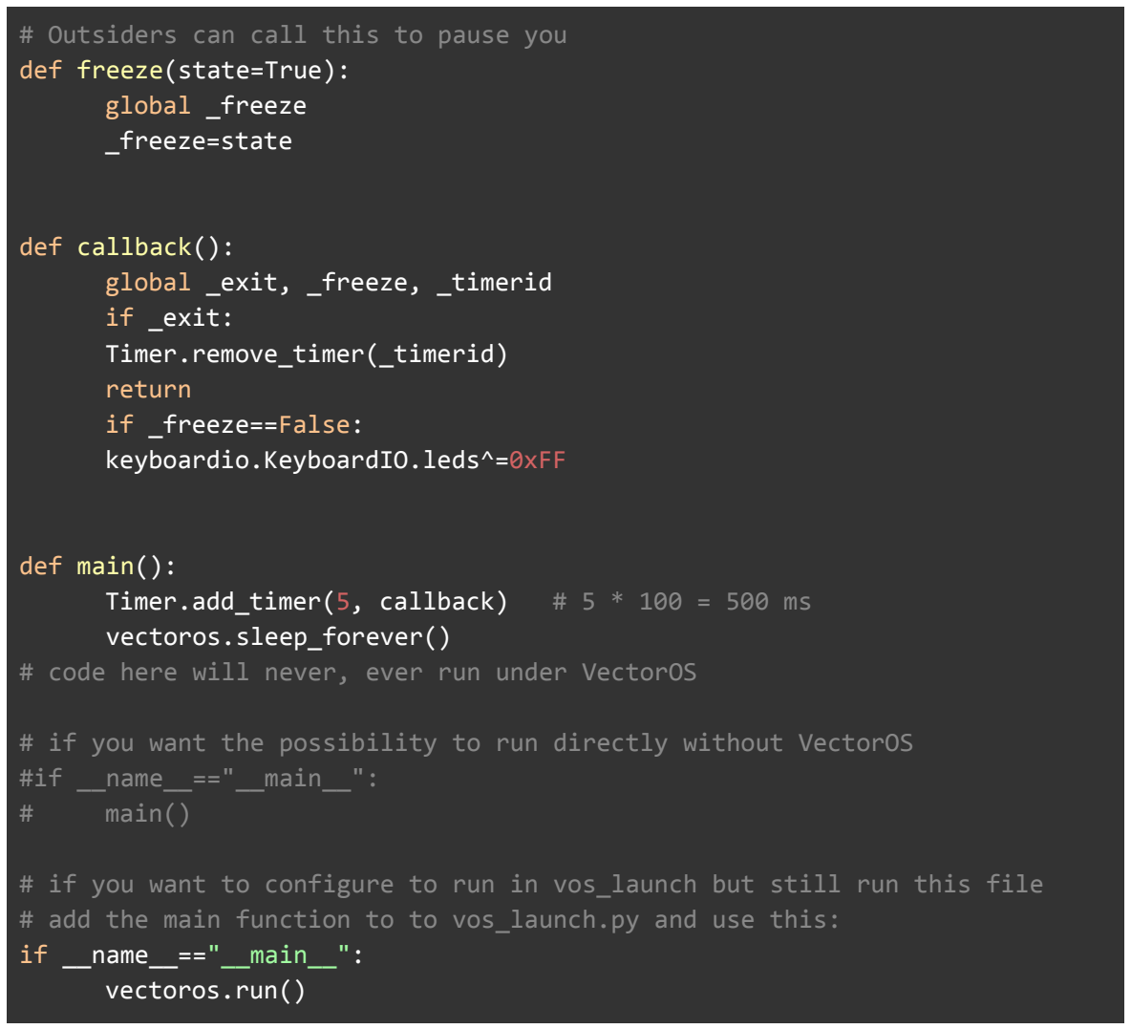
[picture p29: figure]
# Outsiders can call this to pause you def freeze(state=True): global _freeze _freeze=state; def callback(): global _exit, _freeze, _timerid if _exit: Timer.remove_timer(_timerid) return if _freeze==False: keyboardio.KeyboardIO.leds^=0xFF; def main():; vectoros.sleep_forever(); #if __name__=="__main__":; main(); if __name__=="__main__": vectoros.run()

Timer.add_timer(5, callback) # 5 * 100 = 500 ms

# code here will never, ever run under VectorOS

# if you want the possibility to run directly without VectorOS

# if you want to configure to run in vos_launch but still run this file # add the main function to to vos_launch.py and use this:

The main program is just one line and the work happens in a timer callback. The line at the bottom means that when you run the program, it will launch VectorOS. However, unless you’ve configured simple to run, it won’t start this program. To do that, you need to edit vos_launch.py like this (only part of the file is shown):

# list of things to launch from vectoros

# dictionary of tags to functions

launch_list={ "menu": "menudemo", "blinky": "simple", 'sketch': 'sketch', "screen": "screentest"}

# list what you want to start auto (maybe just one thing?) need tag auto_launch_list=["menu", "blinky"]

auto_launch_repl=True

key_scan_rate = 100 # how often to scan the keyboard globally (ms; 0 to do it yourself)

# how often to garbage collect

# if you set this to zero and do nothing else

# garbage collection will be automatic as usual and before new tasks launch gc_thread_rate = 1200

# Base rate for the timer (ms)

timer_base_rate=100
DEBUG_LEVEL_SILENT=-1
DEBUG_LEVEL_SEVERE=0
DEBUG_LEVEL_ERROR=10
DEBUG_LEVEL_WARNING=20
DEBUG_LEVEL_INFO=30
debug_level=DEBUG_LEVEL_INFO

if __name__=="__main__":
import vectoros
vectoros.run()

Note that while this replaces simple for the original blinky task, the menu doesn’t know about it, so the Start/Stop Blinker and Freeze menu items won’t do what you think. However, it would be easy to modify the menudemo.py file to fix that. As an exercise, you could modify vos_state.py to have some pseudo-global variables to control the blinking task and then rewrite both simple.py and blinker.py to use that variable. There are other ways you could this, too, if you want to experiment.

### Inside blinker.py

The blinker.py example is one of the simplest examples provided, yet it shows two different ways to handle repeating tasks. The lower 8 bits of the LED register (inside KeyboardIO or any of its subclasses) are managed by a loop that sleeps for one second total using two sleeps of 500 milliseconds each.

The top 8 bits are managed by a Timer callback that fires every 1.5 seconds. Here is the main function (you can find the entire code on GitHub):

async def vos_main():
global _freeze, _exit

_freeze=False
_exit=False
if vectoros.vectoros_active()==False: keyboardio.KeyboardIO.run(250) timertask=timer.Timer.add_timer(15,callback1500ms) while _exit==False:
if _freeze==False:

keyboardio.KeyboardIO.leds=(keyboardio.KeyboardIO.leds&0xF0)|0xA

await asyncio.sleep_ms(500)
if _freeze==False:
keyboardio.KeyboardIO.leds=(keyboardio.KeyboardIO.leds&0xF0)|5 await asyncio.sleep_ms(500)
_exit=False
vectoros.remove_task('blinky')

### Insider timer.py

The timer.py file has a test program at the bottom that does not directly use VectorOS. However, it does show the different kinds of timers you can set, namely:
- Synchronous timers
- Asynchronous timers
- Synchronous one shots
- Asynchronous one shots
It also uses the API to stop a timer. Here’s the main code:

async def amain():
global onesecid
Timer.run() # this is not needed under VectorOS

# save the timer ID to kill later

onesecid=Timer.add_timer(10,callback1sec) | # every one second
Timer.add_timer(50,callback5sec) | # 5 second synchronous
repeating
Timer.add_timer(100,once,True,True) | # one shot and remove the 1
second tick
Timer.add_timer(55,acallback(),False,True) # one shot

### Inside csvdemo.py

If you would like to use a spreadsheet to calculate a waveform, have a look at csvdemo.py (below).

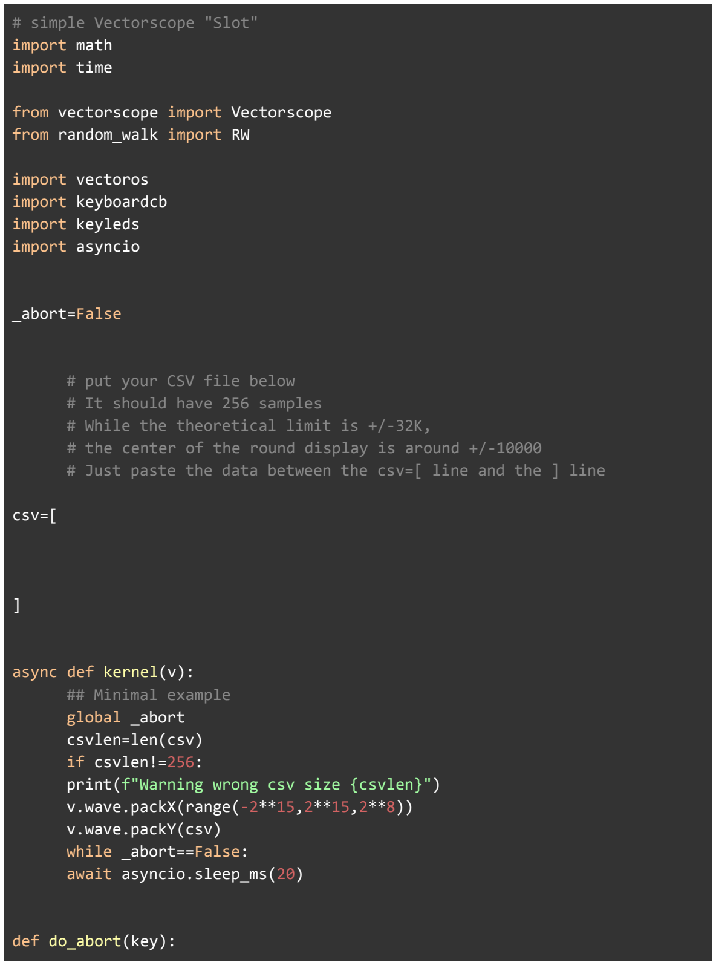
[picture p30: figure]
# simple Vectorscope "Slot" import math import time; from vectorscope import Vectorscope from random_walk import RW; import vectoros import keyboardcb import keyleds import asyncio; _abort=False; # put your CSV file below # It should have 256 samples; csv=[; async def kernel(v): ## Minimal example global _abort csvlen=len(csv) if csvlen!=256:; v.wave.packX(range(-2**15,2**15,2**8)) v.wave.packY(csv) while _abort==False: await asyncio.sleep_ms(20); def do_abort(key):

# While the theoretical limit is +/-32K,

# the center of the round display is around +/-10000

# Just paste the data between the csv=[ line and the ] line

print(f"Warning wrong csv size {csvlen}")

global _abort
_abort=True

async def slot_main(v):
global _abort,_continue
# watch the keys (D to exit) mykeys=keyboardcb.KeyboardCB({ keyleds.KEY_D: do_abort}) await kernel(v)

The slot_main sets up the keyboard and goes to the waveform kernel. The X axis gets a “sweep” ramp and the Y axis comes from the csv list. To create this, use a spreadsheet program to compute 256 values and export them as csv. Paste them into the file and it is ready to go.

### Useful Code Snippets

Generate Sine Wave

int(amplitude * math.sin(time * math.pi/180 * freq)

Call a function with no return that may be async (or not)

try:
async func(1,2,3) # must not return value! except TypeError:
pass

Connect buttons to callbacks:

def cbA(key):
print("A")

def cbB(key):
print("B")
keyab=keyboardcb.KeyboardCB({ keyleds.KEY_A: cbA, keyleds:KEY_B: cbB})

Read multiple key presses in a keyboard callback

def global_cb(key):
if keyleds.KEY_A in keyboardcb.KeyboardCB.current_keys: print("A+Save pressed")

else:
print("Global Save CB")

Launching VectorOS when your program runs
When developing, it is handy to be able to run your program and actually launch the OS. To do this, add the following to your program:

if __name__=="__main__":
import vectoros
vectoros.run()

Dual-mode programs
It is possible to write programs that run under VectorOS or run by themselves. You have to detect that VectorOS is not running and start things like the keyboard loop or the timer loop, if you want to use them.

To do this, you can replace the code you run when __name__ is __main__. You have several options:
1) Set up services you need and call vos_main yourself (or do whatever you want there)
2) Call a function (e.g., main()) to do the setup and either launch vos_main or do whatever you want to do in that function
3) If you run vos_main, you can detect if VectorOS is active using the vos_state.active flag, the vectoros.vectoros_active() call, or you can check if the objects you are interested in have a task field of None. If VectorOS is inactive, you will be responsible for polling the keyboard, for example or, at least, running the KeyboardIO loop with run.

Your exact code will depend on what you want, but you might use something like this:

if __name__=="__main__":
keyboardio.KeyboardIO.run(50) main()

Generate an ascending ramp on the X axis of the scope

ramp = range(-2**15, 2**15, 2**8) v.wave.packX(ramp)

## References

- MicroPython - https://docs.micropython.org/en/latest/
- MicroPython for Raspberry Pi Pico -https://docs.micropython.org/en/latest/library/rp2.html and https://docs.micropython.org/en/latest/library/machine.html and https://docs.micropython.org/en/latest/rp2/quickref.html and https://datasheets.raspberrypi.com/pico/raspberry-pi-pico-python-sdk.pdf
- Raspberry Pi Pico - https://datasheets.raspberrypi.com/pico/getting-started-with-pico.pdf
- LCD Library - https://github.com/russhughes/gc9a01_mpy
- AsyncIO Tutorial -
https://github.com/peterhinch/micropython-async/blob/master/v3/docs/TUTORIAL.md
- Using Context Managers -https://docs.python.org/3/reference/compound_stmts.html#the-with-statement
- Hardware Documentation - https://github.com/Hack-a-Day/Vectorscope
- Generating Sine Waves - https://en.wikipedia.org/wiki/Sine_wave
- GitHub - https://github.com/Hack-a-Day/Vectorscope

### Key and LED Definitions

Key Definitions

ID | Key Number | Description
JOY_ALL | [JOY_PRESS, JOY_UP, JOY_DN, JOY_RT, JOY_LF, JOY_NE, JOY_NW, JOY_SE, JOY_SW] | All Joystick keys (useful for filters)
JOY_DN | 11 | Joystick Down
JOY_E | JOY_RT | Joystick Right
JOY_LF | 14 | Joystick Left
JOY_LT | JOY_LF | Joystick Left
JOY_N | JOY_UP | Joystick Up
JOY_NE | 100 | Joystick Up and Right
JOY_NW | 101 | Joystick Up and Left
JOY_PRESS | 17 | Joystick Center Button Pushed
JOY_RT | 23 | Joystick Right
JOY_S | JOY_DN | Joystick Down
JOY_SE | 102 | Joystick Down and Right
JOY_SW | 103 | Joystick Down and Left
JOY_UP | 20 | Joystick Up
JOY_W | JOY_LF | Joystick West
KEY_A | 8 | A
KEY_ABCD | [KEY_A, KEY_B, KEY_C, KEY_D] | A, B, C, and D buttons (useful for filters)
KEY_ALL | [KEY_MENU, KEY_USER, KEY_SAVE, KEY_A, | All keys (Possible filter although an empty filter should be the same)

ID | Key Number | Description
| KEY_B, KEY_C, KEY_D, KEY_LEVEL, KEY_RANGE, KEY_XY, KEY_WAVE, KEY_SCOPE]
KEY_B | 7 | B
KEY_C | 1 | C
KEY_D | 4 | D
KEY_EVERYTHING | JOY_ALL + KEY_ALL | All keys and joystick
KEY_LEVEL | 5 | Level
KEY_MENU | 19 | Menu
KEY_RANGE | 2 | Range
KEY_SAVE | 22 | Save
KEY_SCOPE | 13 | Scope/Sig Gen
KEY_USER | 24 | User
KEY_WAVE | 16 | Wave
KEY_XY | 10 | XY

LED Definitions

ID | Key Number | LED object Name | Description
LED_SAW | 4 | Saw | Sawtooth LED
LED_SCOPE | 2 | Scope | SCOPE LED
LED_SIG | 1 | Sig | SIG GEN LED
LED_SINE | 32 | Sine | Sine LED
LED_SQ | 16 | Square | Square LED
LED_TRI | 8 | Triangle | Triangle LED
LED_X | 128 | X | X LED
LED_Y | 64 | Y | Y LED

### Files on the Badge

While subject to last minute changes, here’s a list of some of the files you’ll find on your badge and what they are for.

File Name | Description

Startup & Configuration

main.py | Runs on badge startup
menudemo.py | Demo menu (change the menu here)
vos_launch.py | VectorOS configuration file

VectorOS Files

aiorepl.py | REPL for AsyncIO loop
colors.py | Definition of colors
joystick.py | Joystick class
keyboardcb.py | Keyboard to callback functions
keyboardio.py | Runs the single keyboard reading loop

keyboardrepeat.py * | Like keyboardcb, but slower repeat rate
keyleds.py | Define keys, key combinations, and LEDs symbolically
led.py * | Manage LEDs individually
menu.py * | Core of the menu system
romans.py | Vector font
screennorm.py * | Screen management
timer.py | Timers
vectoros.py * | Main VectorOS file
vga1_16x32.py | Base bitmap font
vos_debug.py | Debug logging support
vos_state.py | Information about VectorOS

* File updated or not present on badge

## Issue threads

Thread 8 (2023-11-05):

BOM: TPA321DR  should be TPA321DGN maybe?

tinyledmatrix, 2023-11-05:
Copied from Daves comment in the discord. To not lose this issue in the abyss of the chat.
https://discord.com/channels/879434765390975007/1163976761013436446/1168096977523834940

"
There's some issue with the TPA321, the BOM says TPA321DR is a SOIC, but the footprint is way smaller. It looks more like a TPA321DGN which comes as PowerPAD™ MSOP - but there's no "Power Pad"
"

hexagon5un, 2023-11-11:
Thanks!  This is exactly correct in all respects.  Voja decided that the power pad was unnecessary given the tiny little speaker, but it is indeed that part.  We should change the BOM to match reality.

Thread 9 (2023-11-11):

T1 rotation issue / diode fix

hexagon5un, 2023-11-11:
The p-mosfet has source and drain switched in the circuit diagram, the gerbers, and the production PCB.
There are two good fixes:
One is to flip the mosfet on its back, rotate it around the gate pin (which is correct) and maybe bend the pins down or just blob solder on to connect it.
This doesn't scale well to 550 badges, so we ordered a Schottky diode array with the diodes pointing in the correct direction (common cathode? -- check me!) and did the replacement.

Anyway, this needs to be fixed in the BOM/circuit diagram and the PCB.

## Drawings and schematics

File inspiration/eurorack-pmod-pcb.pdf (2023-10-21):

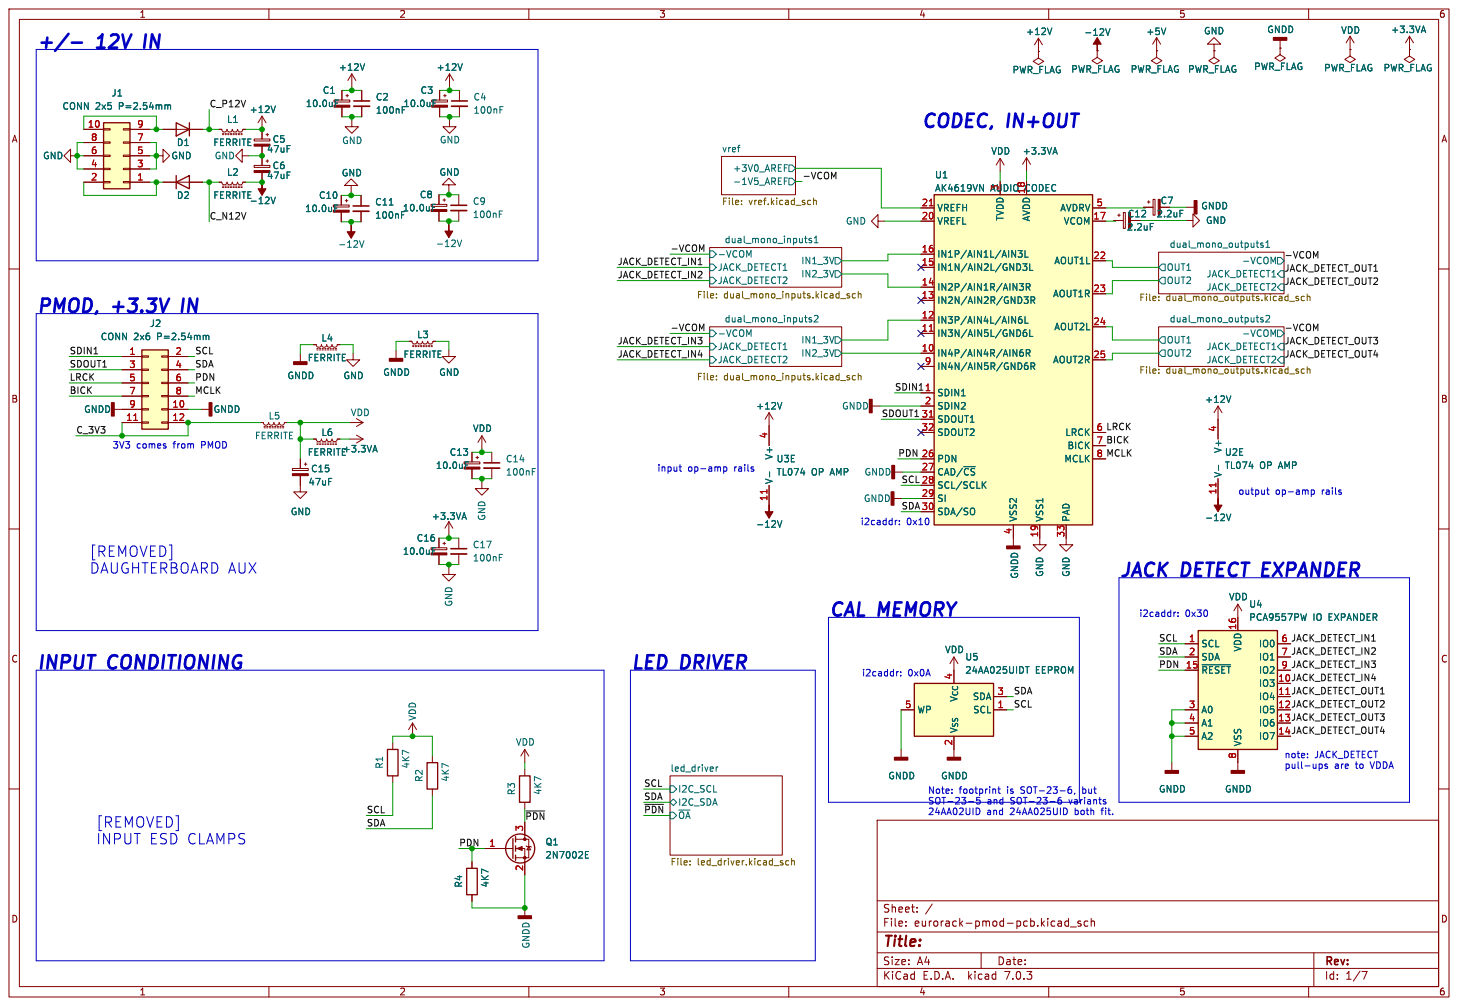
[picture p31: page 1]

Id: 1/7 Title: File: eurorack-pmod-pcb.kicad_sch Sheet: /

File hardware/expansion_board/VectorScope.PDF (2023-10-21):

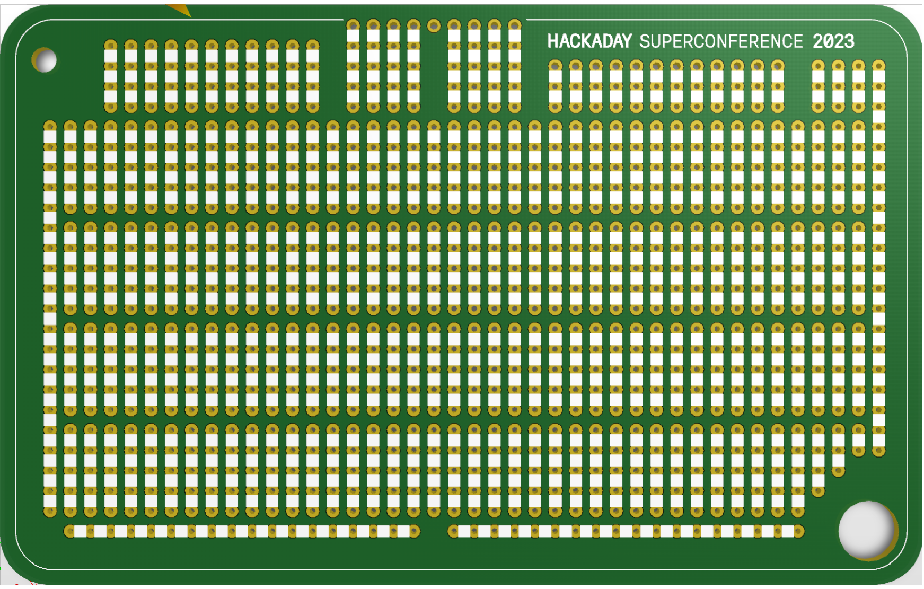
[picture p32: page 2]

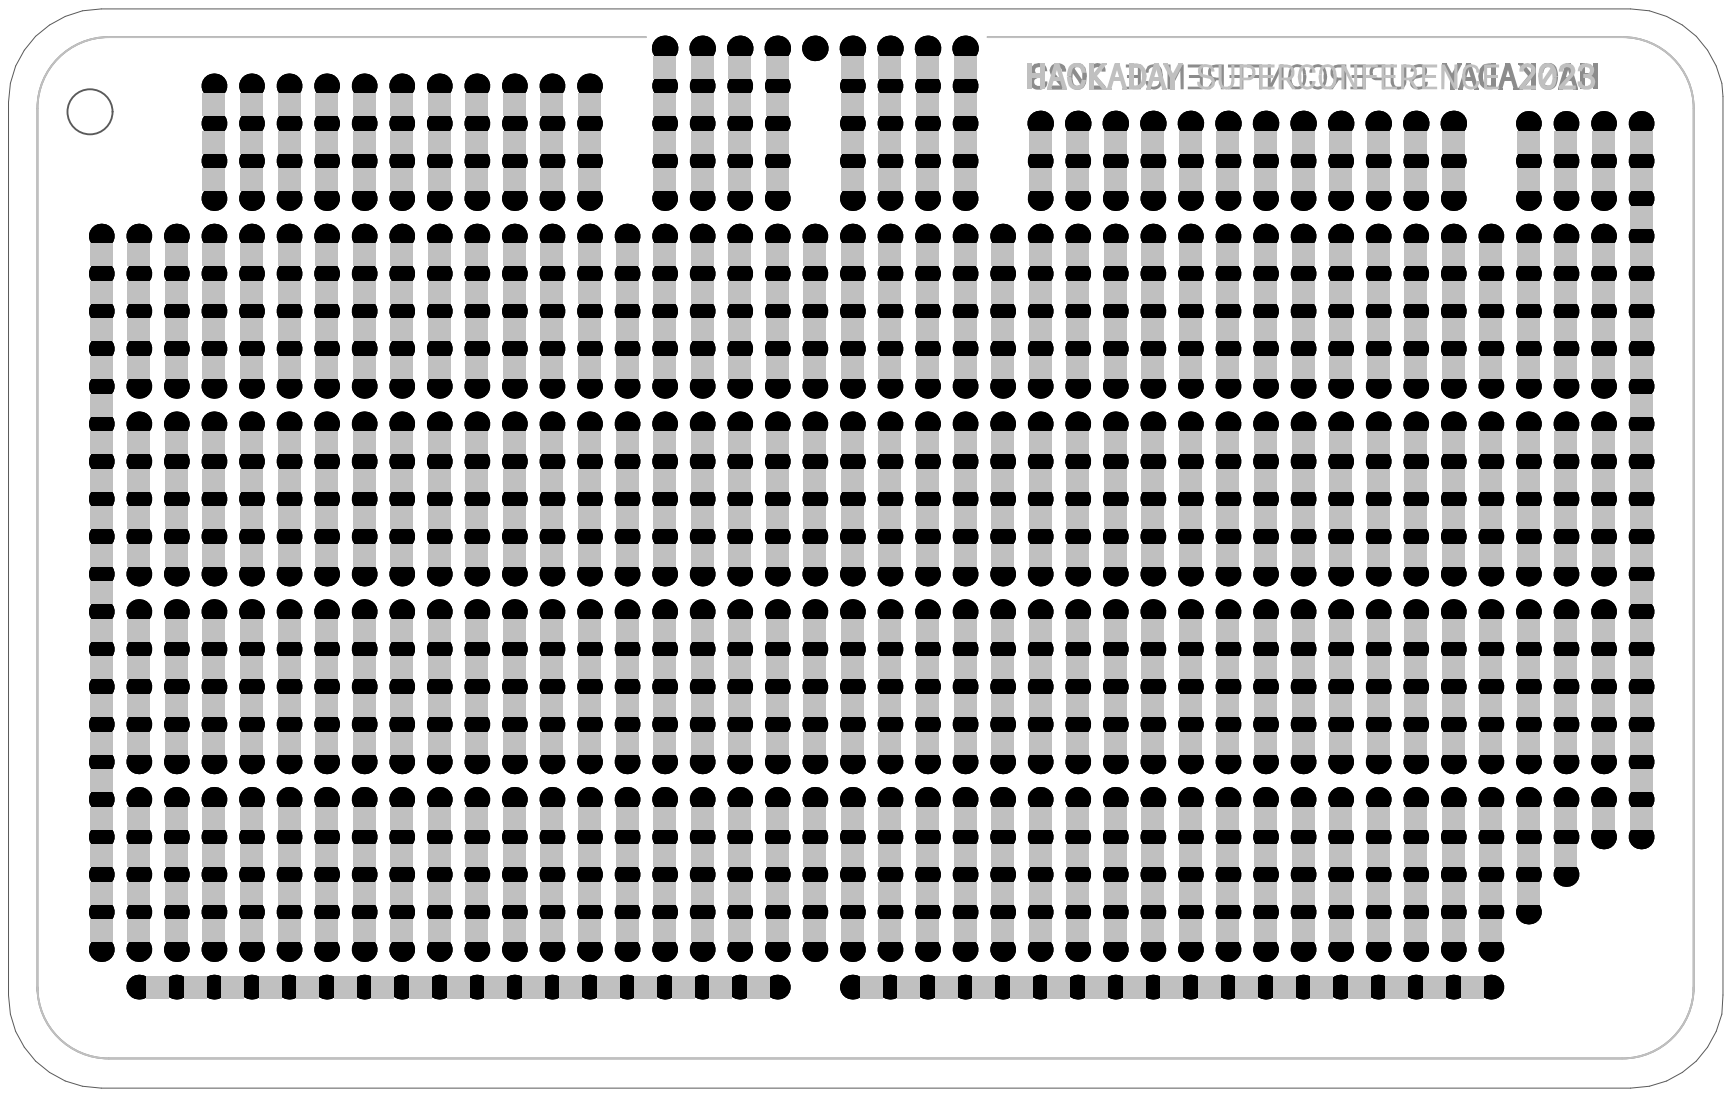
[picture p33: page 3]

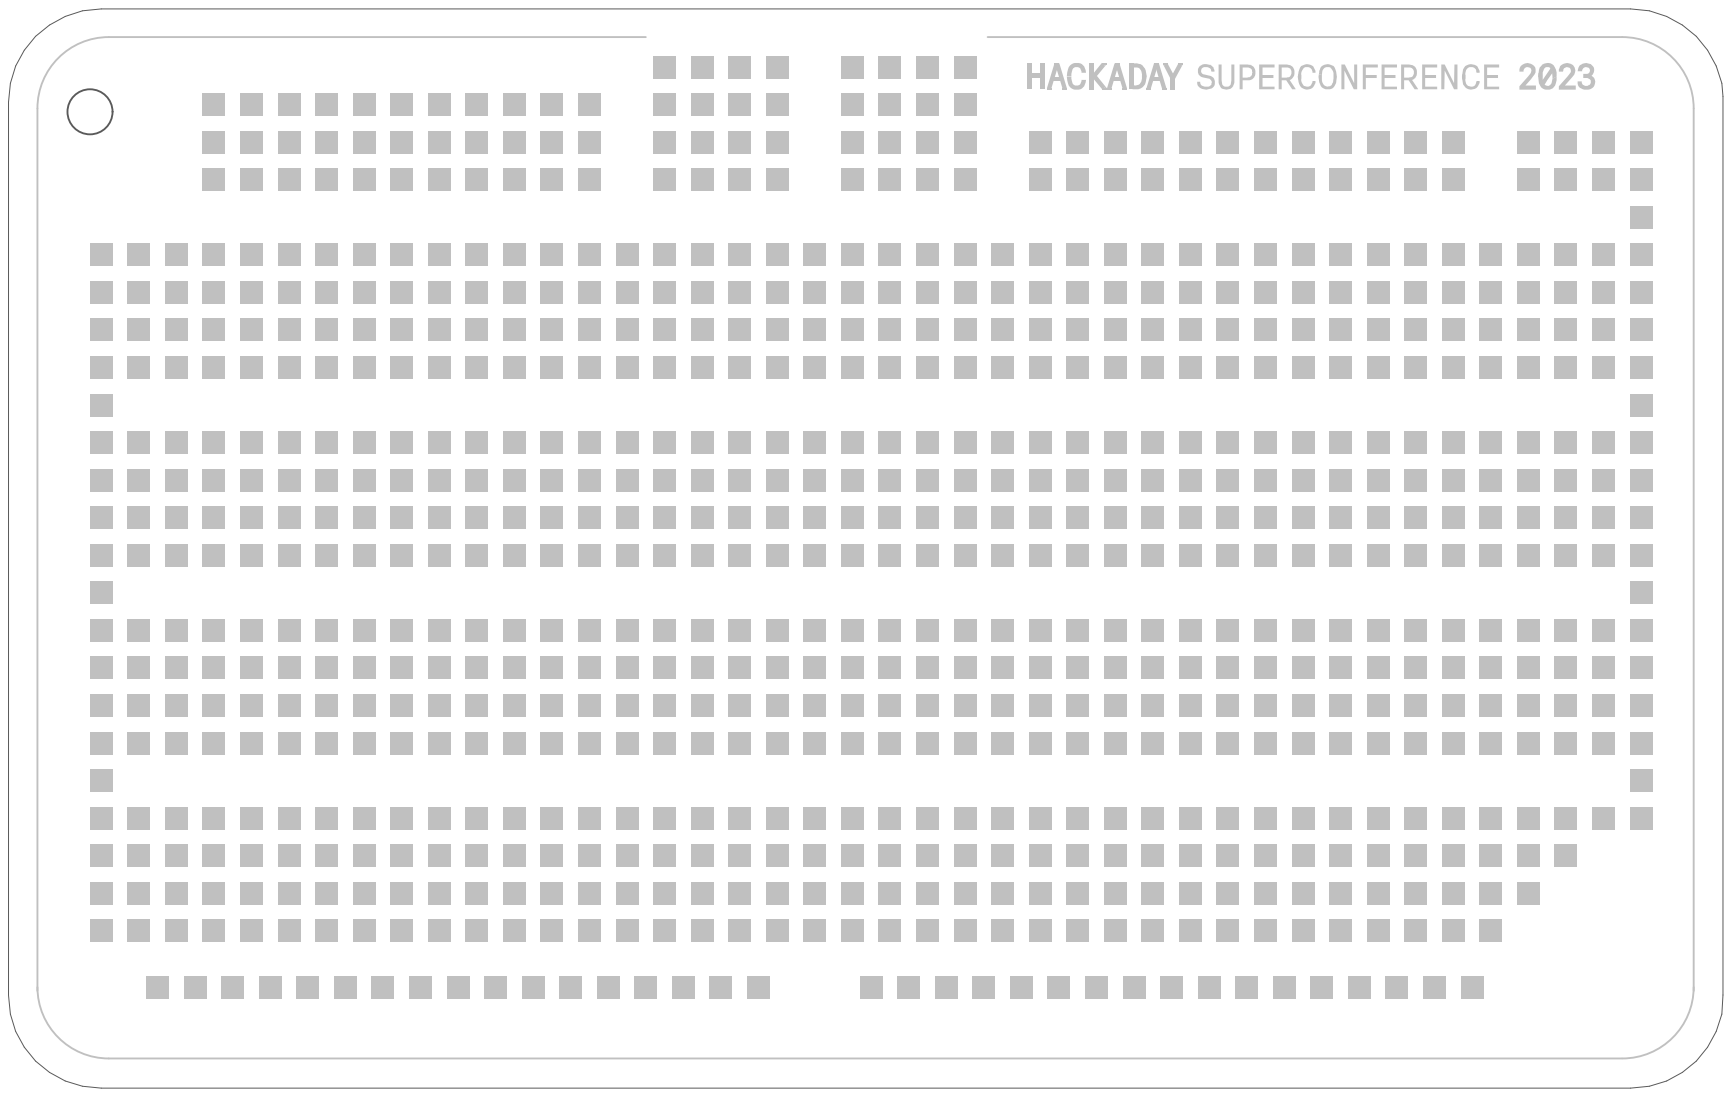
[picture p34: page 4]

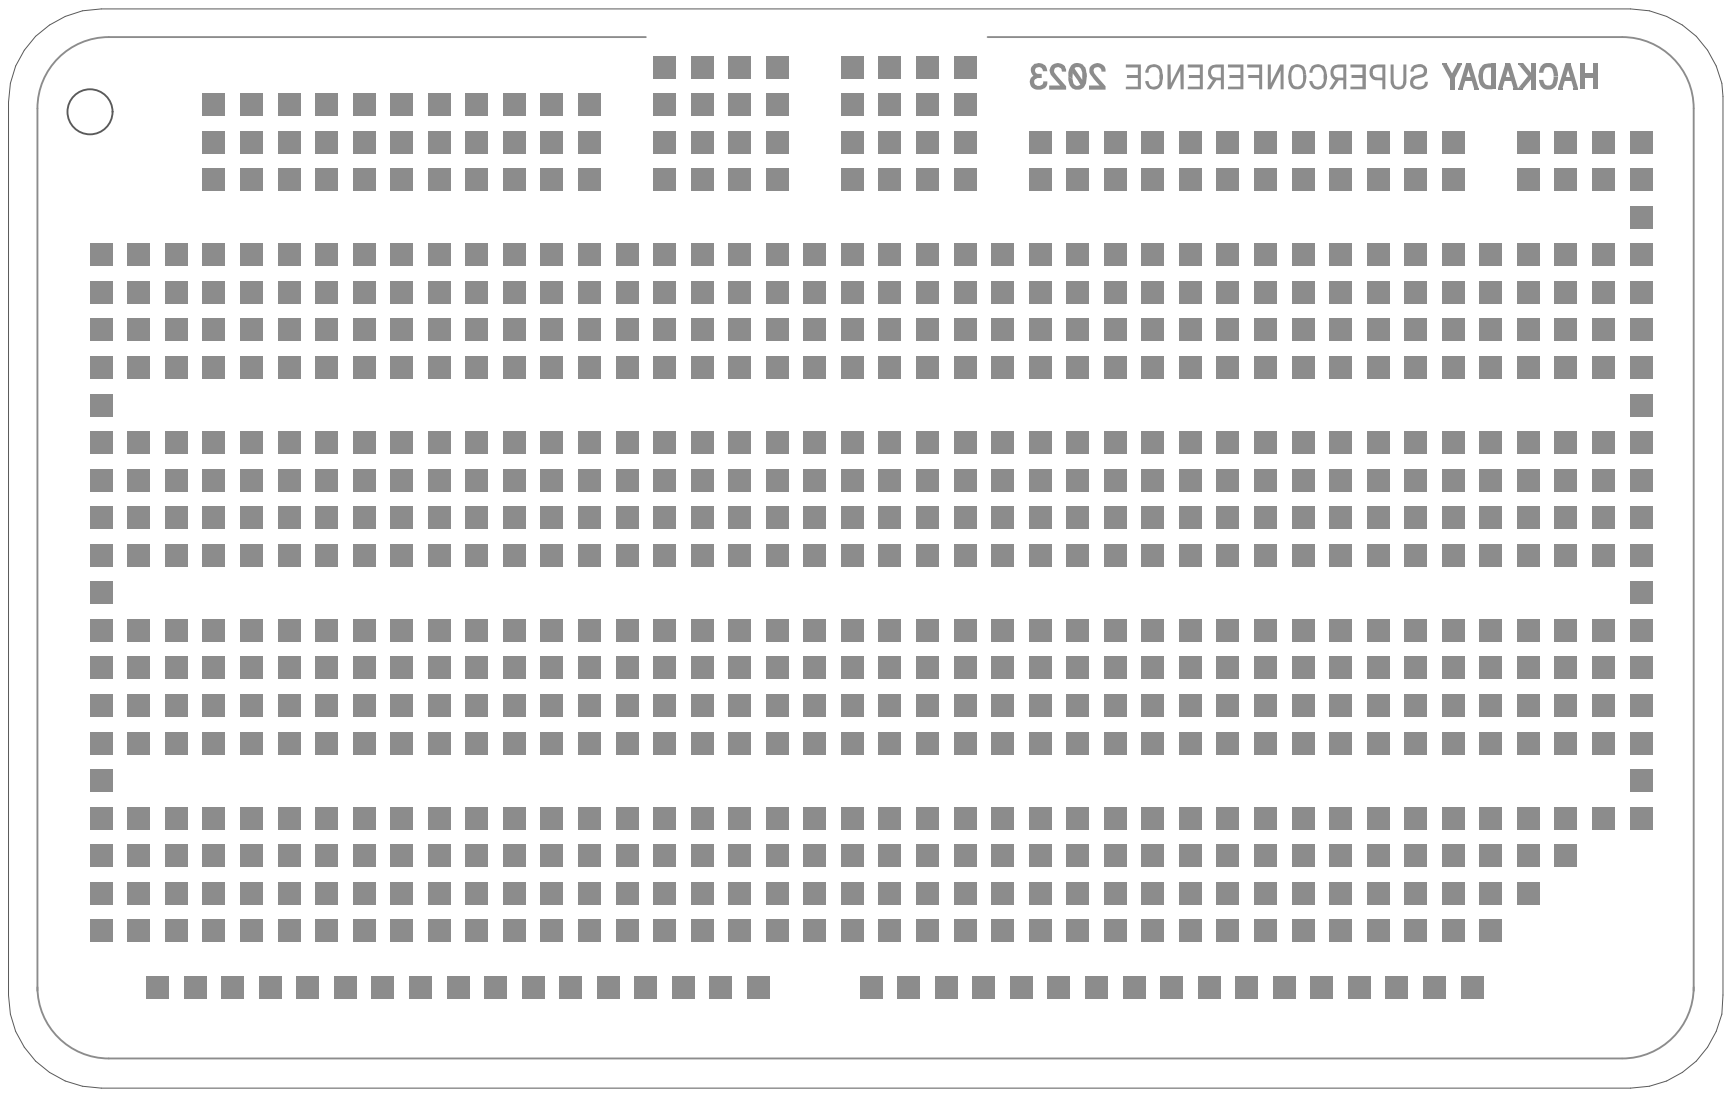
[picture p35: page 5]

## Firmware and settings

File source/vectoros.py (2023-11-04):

import aiorepl
import asyncio
import keyboardio
import screennorm
import timer
from vos_launch import launch_list, auto_launch_list, auto_launch_repl, key_scan_rate, gc_thread_rate, timer_base_rate, vectorscope_slots
from vos_state import vos_state
import gc
from machine import RTC
from machine import reset as m_reset, soft_reset as m_soft_reset
import vos_debug



_VERSION=20231101

_screen=screennorm.ScreenNorm()


async def _sleeper():
    """
    Asynchronous function to sleep forever.

    This function runs a loop that sleeps for 5 seconds and then collects garbage.
    """
    
    while True:
        await asyncio.sleep_ms(gc_thread_rate)
        if vos_state.gc_suspend==False:
            gc.collect()

def reset():
    m_reset()
    
def soft_reset():
    m_soft_reset()


def sleep_forever():
    """
    Function to let non async function wait forever.
    """
    
    asyncio.run(_sleeper())

async def _delayer(n):
    """
    Asynchronous function to delay for n seconds.

    Args:
        n (int): The number of milliseconds to delay.
    """
    
    await asyncio.sleep_ms(n)

def sleep(n):
    """
    Function to delay for n seconds.

    Args:
        n (int): The number of milliseconds to delay.
    """
    vos_debug.debug_print(vos_debug.DEBUG_LEVEL_WARNING,"sleep called which uses asyncio.run")
    asyncio.run(_delayer(n))

def get_screen():
    """
    Function to get the one screen object.

    Returns:
        ScreenNorm: The screen object.
    """
    
    global _screen
    return _screen

async def launch_repl():
        """
        Asynchronous function to start a repl.
        """
        
        vos_state.task_dict['$repl']=asyncio.create_task(aiorepl.task())

async def launch(task_tag):
    """
    Asynchronous function to launch a program by its tag.

    Args:
        task_tag (str): The tag of the program to launch.
        
     Returns:
            Task: The created task.
     """
    if vos_state.gc_suspend==False:
         gc.collect()
    vos_debug.debug_print(vos_debug.DEBUG_LEVEL_INFO,f"launching {task_tag}")
    mod=__import__(launch_list[task_tag])
    try:
        fn=getattr(mod,'vos_main')
    except Exception:
        vos_debug.debug_print(vos_debug.DEBUG_LEVEL_WARNING,f"launch could not find vos_main for {task_tag}. Trying main()")
        fn=getattr(mod,'main')
    try:
        await fn()
    except TypeError:
        pass

        

def launch_task(task_tag):
     """
     Function to create async task to launch.

     Args:
         task_tag (str): The tag of the program to launch.
         
      Returns:
            Task: The created task.
      """
     vos_state.task_dict[task_tag]=asyncio.create_task(launch(task_tag))
     
     
async def launch_vecslot(slot):
    from vectorscope import Vectorscope
    _screen.clear()
    _screen.idle()
    gc.collect()
    vos_state.gc_suspend=True
    vos_state.show_menu=False 
    vos_debug.debug_print(vos_debug.DEBUG_LEVEL_INFO,f"Launching slot {slot}:{vectorscope_slots[slot]}")
    mod=__import__(vectorscope_slots[slot])
    fn=getattr(mod,'slot_main')
    v = Vectorscope(screen_running=True)
    try:
        vos_debug.debug_print(vos_debug.DEBUG_LEVEL_INFO,"launching")
        await fn(v)
    except TypeError:
        pass
    except Exception as e:
        print("launch exception",e)
    finally:
        vos_debug.debug_print(vos_debug.DEBUG_LEVEL_INFO,"Slot done, reboot!")
#        await asyncio.sleep(5)
        reset()
    
    
def remove_task(t):   
     """
     Function to remove a task. Note that this does not stop the task, just takes it out of the list

     Args:
         t (str): The tag of the task to remove.
      """
     
     try:   
         vos_state.task_dict.pop(t)
     except Exception:
         pass

_gc_exit=False

async def _gc_thread(ms):
     """
     Asynchronous function for optional thread to garbage collect occasionally.

     Args:
         ms (int): The number of milliseconds to sleep between garbage collections.
      """
     global _gc_exit
     while _gc_exit==False:
         await asyncio.sleep_ms(ms)
         if vos_state.gc_suspend:
             continue
         vos_debug.debug_print(vos_debug.DEBUG_LEVEL_INFO,"Garbage collection starting")
         gc.collect()
         gc.threshold(gc.mem_free() // 4 + gc.mem_alloc())
     vos_debug.debug_print(vos_debug.DEBUG_LEVEL_INFO,"Garbage collection thread exit")


def vectoros_active():
     """
     Function to test if we are active.

     Returns:
         bool: True if active, False otherwise.
      """
     
     return vos_state.active
    
_vectoros_runafter=None

def set_global_exception():
     """
     Function to catch exceptions. 
      """
     def handle_exception(loop,context):
         import sys
         if context["exception"].args[0]=="__vectoros-exit__":
             vos_state.run_after=context["exception"].args[1]
         else:
             sys.print_exception(context["exception"])
         sys.exit()

     
     loop=asyncio.get_event_loop()
     loop.set_exception_handler(handle_exception)
     
async def vectoros_startup(autolaunch=True):
    """
    Function to start services (called by main)
    
    Args:
    autolaunch (bool): True to launch autostart programs (default)
    """
    global _VERSION
    vos_state.version=_VERSION
    vos_debug.debug_print(vos_debug.DEBUG_LEVEL_INFO,f"VectorOS {_VERSION} starting",RTC().datetime())
# honor gc thread request    
    if gc_thread_rate!=0:
        gc.disable()
        vos_state.task_dict['$gc']=asyncio.create_task(_gc_thread(gc_thread_rate))
# spin up system-level keyboard polling (see keyboardcb and joystick)
    if key_scan_rate!=0:
        vos_state.task_dict['$key']=keyboardio.KeyboardIO.run(key_scan_rate)
# spin up timer infrastructure
    if timer_base_rate!=0:
        vos_state.task_dict['$timer']=timer.Timer.run()
# at this point, we consider ourselves running        
    vos_state.active=True
# launch repl if requested
    if autolaunch:
        if (auto_launch_repl):
            await launch_repl()
# run auto launch stuff from vos_launch        
        for t in auto_launch_list:
            vos_state.task_dict[t]=asyncio.create_task(launch(t))
        vos_debug.debug_print(vos_debug.DEBUG_LEVEL_INFO,"VectorOS started",RTC().datetime())
            

# shut down our service (but not apps)
def vectoros_shutdown(deactivate=True):
    """
    Function to shut down vectoros services
    """
    global _screen, _gc_exit
    vos_debug.debug_print(vos_debug.DEBUG_LEVEL_INFO,"VectorOS shutting down",RTC().datetime())
    _screen.idle()
    _screen=None
    keyboardio.KeyboardIO.cancel()
    del vos_state.task_dict['$key']
    timer.Timer.cancel()
    del vos_state.task_dict['$timer']
    _gc_exit=True
#    vos_state.task_dict['$gc'].cancel()
    del vos_state.task_dict['$gc']
    for x in vos_state.task_dict:
        vos_state.task_dict[x].cancel()
    if (deactivate):
        vos_state.active=False
    asyncio.get_event_loop().set_exception_handler(None)
    gc.collect()
    vos_debug.debug_print(vos_debug.DEBUG_LEVEL_INFO,"VectorOS shut down",RTC().datetime())
    
def ext_run(cmd):
    """
    Function to exit VectorOS and run a program
    """
    gc.collect()
    vos_debug.debug_print(vos_debug.DEBUG_LEVEL_INFO,f"external run {cmd}")
    raise Exception("__vectoros-exit__",cmd)



# get all set up
async def main():
    """
    Asynchronous main function to set up the system.

    This function sets up exception handling, starts the garbage collection thread, keyboard polling, and timer infrastructure,
    launches the repl if requested, imports modules from vos_launch, and runs auto launch stuff from vos_launch.
    """
# catch any strange exceptions
    set_global_exception()
    await vectoros_startup()
    await _sleeper()
    
# This is the main entry point that starts everything    
def run():
    """
    Function to run the main function.

    This function runs the main function and resets the event loop.
    """
    global _vectoros_runafter, _vectoros_runaftermod
    cmd=None
    while True:
        try:
            asyncio.run(main()) # do not create tasks before this point!
        except SystemExit as se:
            break    # catch sys.exit
        except Exception as e:
            print(e)                        # shouldn't really run
            print(hasattr(e,'arg'))
            if hasattr(e,'arg'):
                if e.arg[0]=='__vectoros-exit__':
                    _vectoros_runafter=e.args[1]
                else:
                    print(e)
            else:
                print(e)
# This code launches a program after vectoros shutdown
# The "single core" method works more reliably but if it is
# in the second core causes stack errors (vos_state._xthreading==0)
# The vos_state._xthreading==1 case works for multicore but
# requrires a small server on the main core
#This mostly works in single core mode
        finally:
            if vos_state._xthreading==0:      # single core mode 
                if vos_state.run_after != None:					# as we exit, set up any pending command
                    cmd=vos_state.run_after
                    vos_state.run_after=None
                else:
                    vos_debug.debug_print(vos_debug.DEBUG_LEVEL_INFO,"reset event loop")
                    asyncio.new_event_loop()
                if cmd!=None:
                     vectoros_shutdown()
                     vos_state.gc_suspend=True
                     asyncio.sleep_ms(250)   # hope the gc thread dies if it hasn't already
                     import sys
                     del sys.modules['screennorm']
                     del sys.modules['aiorepl']
                     del sys.modules['romans']
                     del sys.modules['vga1_16x32']
                     gc.collect()
                     exec(cmd)
            else:                        # multicore mode (requires start w/split_vos.py)
                if vos_state.run_after != None:					# as we exit, set up any pending command
                    print("core 1 passing back to zero")
                    import sys
                    del sys.modules['screennorm']
                    del sys.modules['aiorepl']
                    del sys.modules['romans']
                    del sys.modules['vga1_16x32']
                    del sys.modules['keyboardio']
                    del sys.modules['timer']
                    vos_state.gc_suspend=True
                    asyncio.sleep_ms(250)   # hope the gc thread dies if it hasn't already
                    gc.collect()
                    vectoros_shutdown(False)
                    gc.collect()
                else:
                    print("Resetting event loop")
                    asyncio.new_event_loop()
    if vos_state._xthreading==1:
       gc.collect()
       vos_state.active=False
    else:
        pass

if __name__=="__main__":
    run()


    
    
        

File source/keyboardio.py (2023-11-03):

import asyncio
import keyleds
from machine import SoftSPI, Pin
import vos_debug

class KeyboardIO:
    """
    A class that reads keys from the board and manages LEDs. 

    Attributes:
        leds (int): The LEDs to write out.
        task (Task): The task for the keyboard polling loop.
        current_keys (list): The list of currently pressed keys.
        _timeout (int): The poll rate in ms.
        _spi (SoftSPI): The SPI interface.
        _latch_load (Pin): The shift-register load pin.
        _button_sense (list): The two columns of button matrix.
        _user_sense (Pin): The user sense pin.
        _subscribers (list): The list of subscribers who want to know about keys.
        _prev (list): The list of keys that were down in the last poll.
        _capture (KeyboardIO): The subscriber that hogs all the keyboard.
    """
    
    leds=0   
    task=None          
    current_keys=[]   

    _timeout=100  
    _spi = SoftSPI(baudrate=500_000,  sck=Pin(0), mosi=Pin(1), miso=Pin(19)) 
    _spi.init()
    _latch_load = Pin(16, mode=Pin.OUT, value=0)                     
    _button_sense = [Pin(17, mode=Pin.IN), Pin(18, mode=Pin.IN)] 
    _user_sense = Pin(19, mode=Pin.IN)  
    _subscribers=[]    
    _prev=[]           
    _capture=None
    _cancel=False

    def __init__(self, attach=True):
        """
        The constructor for KeyboardIO class.

        Args:
            attach (bool): A flag to indicate if the keyboard should be attached during initialization. Default is True.
        """
        
        self.subref=self.key 
        if (attach):
            self._subscribers.append(self.subref);

    def __enter__(self):
        return self
    
    def __exit__(self, exc_type, exc_val, exc_tb):
        if self._capture==self.subref:
            self._capture=None
        self.detach()

    def capture(tf=True):
        """
        Function to grab all keyboard events for this instance.

        Args:
            tf (bool): A flag to indicate if the keyboard events should be captured. Default is True.

        Returns:
            bool: True if the capture was successful, False otherwise.
        """
        
        if tf==True and self._capture!=None and self._capture!=self.subref:
            return false
        if tf==False and self._capture!=self.subref:
            return false
        if tf==True:
            self._capture=self.subref
        else:
            self._capture=None 
        return True 

    @classmethod
    async def _run(cls, timeout_ms=100):
        """
        Class method to run the class level "server".

        Args:
            timeout_ms (int): The timeout in ms. Default is 100.

        Returns:
            Task: The created task.
        """
        
        if timeout_ms!=0:
            cls._timeout=timeout_ms
        cls.task=asyncio.create_task(cls._job())
    
    @classmethod
    def run(cls,timeout_ms=100):
        """
        Class method to launch the event loop without having to create a task yourself.

        Args:
            timeout_ms (int): The timeout in ms. Default is 100.

        Returns:
            Task: The created task.
        """
        
        return asyncio.create_task(cls._run(timeout_ms))
    
    @classmethod
    async def _job(cls):
        """
        Class method for the actual polling task.
        
        This method runs a loop that sleeps for a specified timeout and then scans the keyboard.
        
         Returns:
            Nothing
        """
        vos_debug.debug_print(vos_debug.DEBUG_LEVEL_INFO,"Starting keyboard loop")
        while cls._cancel==False:
             await asyncio.sleep_ms(cls._timeout)
             await cls._do_scan()
        vos_debug.debug_print(vos_debug.DEBUG_LEVEL_INFO,"KEYIO exiting")

    @classmethod
    def cancel(cls):
         """
         Class method to cancel the polling task.
         """
         cls._cancle=True
         cls.task.cancel()
    
    def attach(self):
         """
         Method to attach a subscriber to the keyboard.

         This method adds a subscriber to the list of subscribers if it is not already there.
         """
         
         if self.subref not in self._subscribers:  
             self._subscribers.append(self.subref)
    
    def detach(self):
         """
         Method to detach a subscriber from the keyboard.

         This method removes a subscriber from the list of subscribers if it is there.
         """
         
         if self.subref in self._subscribers:
             self._subscribers.remove(self.subref)

    @classmethod
    async def _do_scan(cls):
         """
         Class method to scan the keyboard and process all keys.
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

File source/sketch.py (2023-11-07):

import screennorm
import keyboardcb
import keyleds
import joystick
import vectoros
from vos_state import vos_state
import gc9a01
import gc   # need to read files so we can garbage collect between

# little etch-a-sketch demo

pendown = True           # start off with pen down
color = gc9a01.BLACK     # start off black

# To maintain the cursor we need a bit map which is slow
# so less is more. Also pixels are tiny
# so 40 is a good compromise (40x40 drawing area)
SIZE=40     
PIXSIZE=240//SIZE            # size of each "pixel"

# start cursor in the middle
cursor_x = (SIZE+1)//2
cursor_y = (SIZE+1)//2

# This will be the backing store for the screen
model=[]

stopflag=False  # stop when true

# clear the mdoel with color c (does not draw; see cursor)
def fill_model(c):
    global model
    model=[[c for i in range(SIZE)] for j in range(SIZE)]

def save_model(filename):
    global model
    try:
        with open(filename, 'w') as f:
            gc.collect()
            for row in model:
                f.write(' '.join(map(str, row)) + '\n')
                gc.collect()
        return True
    except:
        return False

def load_model(filename):
    global model
    model=[]
    gc.collect()
    try:
        with open(filename, 'r') as f:
            for line in f:
                numbers=line.split()
                gc.collect()
                model.append([int(x) for x in numbers])
        cursor()
        return True
    except:
        return False


# update screen and overlay cursor (or just cursor area if blit==False)
def cursor(blit=True):
    global model
    global cursor_x
    global cursor_y
    global PIXSIZE
    global pendown
    ccolor=gc9a01.color565(0xC0,0xFF,0x80)
    if pendown:
        ccolor=gc9a01.color565(0xFF,0x80,0x80)
        keyboardcb.KeyboardCB.leds=(keyboardcb.KeyboardCB.leds and not keyleds.LED_SCOPE) or keyleds.LED_SIG
    else:
        keyboardcb.KeyboardCB.leds=(keyboardcb.KeyboardCB.leds and not keyleds.LED_SIG) or keyleds.LED_SCOPE
    if blit:
        for x in range(SIZE):
            for y in range(SIZE):
                screen.tft.fill_rect(x*PIXSIZE,y*PIXSIZE,PIXSIZE,PIXSIZE,model[x][y])
    else:  # only draw around the cursor
        for x in range(-1,2):
            for y in range(-1,2):
                nx=cursor_x+x
                ny=cursor_y+y
                screen.tft.fill_rect(nx*PIXSIZE,ny*PIXSIZE,PIXSIZE,PIXSIZE,model[nx][ny])
    screen.tft.fill_rect(cursor_x*PIXSIZE,cursor_y*PIXSIZE,PIXSIZE,PIXSIZE,ccolor)

# flip pen/up down on joystick button (non-repeating)
def joybtn(key):
    global pendown
    pendown=not pendown
    cursor(False)   # update cursor color

# normal joystick commands
def joycmd(key):
    global pendown, cursor_x, cursor_y
    x=0
    y=0
    if key==keyleds.JOY_N:
        y=-1
    elif key==keyleds.JOY_S:
        y=1
    elif key==keyleds.JOY_E:
        x=1           
    elif key==keyleds.JOY_W:
        x=-1
    elif key==keyleds.JOY_NW:
        y=-1
        x=-1
    elif key==keyleds.JOY_SW:
        y=1
        x=-1
    elif key==keyleds.JOY_NE:
        y=-1
        x=1
    elif key==keyleds.JOY_SE:
        y=1
        x=1
    if x!=0 or y!=0:
        newx=cursor_x+x
        if newx>=0 and newx<SIZE-1:
            cursor_x=newx
        newy=cursor_y+y
        if newy>=0 and newy<SIZE-1:
            cursor_y=newy
        if pendown:
            model[cursor_x][cursor_y]=color
        cursor(False)

# command keys (A=Black, B=Red, C=Green, D=Blue, User=Clear)
def red(key):
    global color
    if keyleds.KEY_SAVE in keyboardcb.KeyboardCB.current_keys:
        save_model("B.sketch")
    elif keyleds.KEY_USER in keyboardcb.KeyboardCB.current_keys:
        load_model("B.sketch")
    else:
        color=gc9a01.RED
        keyboardcb.KeyboardCB.leds=(keyboardcb.KeyboardCB.leds&03) or keyleds.LED_SQ
    
def green(key):
    global color
    if keyleds.KEY_SAVE in keyboardcb.KeyboardCB.current_keys:
        save_model("C.sketch")
    elif keyleds.KEY_USER in keyboardcb.KeyboardCB.current_keys:
        load_model("C.sketch")
    else:
        color=gc9a01.GREEN
        keyboardcb.KeyboardCB.leds=(keyboardcb.KeyboardCB.leds&03) or keyleds.LED_SAW
    
def blue(key):
    global color
    if keyleds.KEY_SAVE in keyboardcb.KeyboardCB.current_keys:
        save_model("D.sketch")
    elif keyleds.KEY_USER in keyboardcb.KeyboardCB.current_keys:
        load_model("D.sketch")
    else:    
        color=gc9a01.BLUE
        keyboardcb.KeyboardCB.leds=(keyboardcb.KeyboardCB.leds&03) or keyleds.LED_TRI
    
def black(key): 
    global color,model
    if keyleds.KEY_SAVE in keyboardcb.KeyboardCB.current_keys:
        save_model("A.sketch")
    elif keyleds.KEY_USER in keyboardcb.KeyboardCB.current_keys:
        load_model("A.sketch")
    else:    
        color=gc9a01.BLACK
        keyboardcb.KeyboardCB.leds=(keyboardcb.KeyboardCB.leds&03) or keyleds.LED_SINE

def white(key):   # erase
    global color
    color=gc9a01.WHITE

def cls(key):
    fill_model(gc9a01.WHITE)
    cursor()

def menu(key):       # exit and return to menu
    global stopflag
    print("menu")
    if vos_state.active:
        stopflag=True
        joy.detach()
        btn.detach()
        csel.detach()

# create our screen and keyboard/joystick
screen=screennorm.ScreenNorm()
joy=joystick.Joystick(joycmd,attach=False)
btn=keyboardcb.KeyboardCB(joybtn,keyleds.JOY_PRESS,attach=False)  # no repeat
csel=keyboardcb.KeyboardCB({ keyleds.KEY_LEVEL: white, keyleds.KEY_A: black,
                             keyleds.KEY_B: red, keyleds.KEY_C: green, keyleds.KEY_D: blue, keyleds.KEY_USER: cls,
                             keyleds.KEY_MENU: menu},
                           attach=False)
                             

import asyncio
import gc

async def vos_main():
    global stopflag
    if keyboardcb.KeyboardCB.task==None:
        keyboardcb.KeyboardCB.run(100)  # start keyboard service
    cls(None)                 # zero out model and draw
    joy.attach()
    btn.attach()
    csel.attach()

    while stopflag==False:
        await asyncio.sleep(5)
        if vos_state.active==False:
            gc.collect()
    stopflag=False   # ready for next time
    vos_state.show_menu=True
    vectoros.remove_task('sketch')
    print("Exiting")


def main():
    asyncio.run(vos_main())

if __name__ == "__main__":
    main()   # need gc if you try to run stand alone

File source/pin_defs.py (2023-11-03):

## Hardware GPIO # pin defines

## Screen pins
sck   = const(2)
data  = const(3)
reset = const(4)
dc    = const(5)

## there are a number of libs that require pins that we don't provide
## pass them the on-board LED.  It's unlikely to hurt.
throwaway = const(25)
debug     = const(27)

user_button    = const(19)
audio_shutdown = const(22)

## Codec pins
## clocks
mclk      = const(7)
bit_clock = const(8)
lr_clock  = const(9)
## data
sd_in     = const(13) ## In 3/4 (Y=L, X=R)
sd_out    = const(10) ## Out 1/2 (Y=L, X=R)
## config
pdn       = const(6)
i2c_scl   = const(21)
i2c_sda   = const(20)




## some globally useful pin inits
# debug_pin          = machine.Pin(debug, machine.Pin.OUT, value=0)
# audio_shutdown_pin = machine.Pin(audio_shutdown, machine.Pin.OUT, value=1)
# user_button        = machine.Pin(user_button, machine.Pin.IN)


#sd_in=Pin(13, Pin.IN) ## In 3/4 (Y=L, X=R)
#sd_out=Pin(10, Pin.OUT, value=0) ## Out 1/2 (Y=L, X=R)

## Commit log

2023-10-21 hello world!
    pulling from private repo into public
    [Badge2023_BOM_R1.xlsx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]
2023-10-21 Added KiCad board file
    Auto converted using KiCad 7.0.8 and manually fixed internal mechanical holes and added 3D models to components. Some 3D models are not part of the standard KiCad library and those will NOT load correctly.
2023-11-03 Fix filenames in screentest.py
    [screentest.py]
2023-11-04 fixed supercon menu to fix gc bug crash
    [supercon_menu.py]
2023-11-11 added audio shutdown pin to vectorscope class
2023-12-01 Update planets.py
    Reset auto-advance timer on each manual advance
    [planets.py]
2024-04-13 fix lissajous mode to not turn off audio
    you can't control it from your code now, but only from the system menu
    [vectorscope.py]
